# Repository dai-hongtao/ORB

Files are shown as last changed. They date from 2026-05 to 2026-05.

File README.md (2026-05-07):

# ORB

ORB 是一套开源模块化桌面性能指示系统：使用 6E2 真空管和指针式仪表，实时监控 CPU 负载、内存压力、硬盘读写、网速等信息。

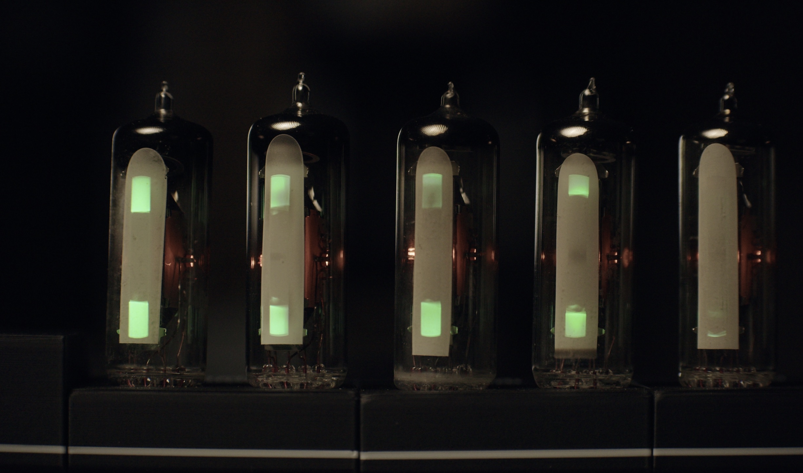
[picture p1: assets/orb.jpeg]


## 系统架构

ORB 由三种模块组成：

| 模块 | 名称 | 功能 |
| --- | --- | --- |
| 源 | Origin | 电源 + 主控 |
| 曜 | Radiance | 真空管模块 |
| 衡 | Balance | 指针仪表模块 |

你需要：

- 源 x 1（必须）
- 曜 / 衡 x N（自由组合）

ORB 最多支持 8 个拓展模块（即 16 个显示单元）。

## 首次启动

新设备首次启动时，先单独给源模块上电。  
源模块会发射一个热点，用手机连接这个热点，并在设置页中填写 SSID、密码，即可将源模块接入 Wi-Fi。  
随后，打开电脑客户端，客户端会识别到局域网中的源模块，并自动连接。

## 模块注册

曜/衡模块通过 I2C 协议与源模块通信。  
曜/衡模块首次连接源模块时，需逐一注册，并分配 I2C 地址，具体操作如下：

- 将**一个**新的曜/衡模块连接至源模块，上电开机。
- 客户端识别到新设备后，会弹出提示，用户添加设备后，即注册成功。
- 断电，插入下一个新模块，开机，继续注册剩余模块。

**注意：每次只能注册 1 个模块，不能同时注册多个新模块。I2C 设备不支持热拔插，请先插入新的模块后，再开机上电，否则系统无法识别新设备。**

I2C 地址分配规则：

曜/衡模块使用的 DAC 拥有 8 个可写的 I2C 地址，因此 ORB 最多可以同时连接 8 个模块。  
DAC 出厂的默认地址是 `0x60`，当源模块识别到地址为 `0x60` 的 I2C 设备时，即会判断为新模块。  
新模块注册时，系统会将该新设备分配一个 `0x61` - `0x67` 的地址。  
第 8 个模块会被分配为默认的 `0x60`。  
如 `0x60` - `0x67` 全部被占用，再插入新的模块，系统将不再识别，也无法控制这个模块。

如出现误操作，为模块写入了重复的地址，请删除该模块并重新添加，或在维护模式中，手动为指定模块写入 I2C 地址。  

I2C 注册表会保存在 MCU 中。如果更换上位机，相关设置也会保留。

## 模块校准

因不同电子管厂生产的 6E2 一致性较差，建议在模块注册后，进行一次校准。  
在客户端中选中某根电子管，点击 `校准`（如果不确定选中的是哪根电子管，可以点击 `寻找`，对应的电子管会亮起）。  
跟随客户端提示，依次将电子管指示条手动设置到 50%、0%、25%、100%、75%，即可完成校准。  
每根电子管只需校准 1 次，校准文件会保存在 MCU 中。更换新的电子管后，需再次进行校准。

衡模块的指针仪表，校准流程同曜模块。

## 客户端操作

在客户端中，你可以所见即所得地设置各个模块。

- 将要显示的参数拖动到电子管/仪表上，即可设置每个模块的显示内容。如一根电子管上绑定了多个CPU核心，则会取平均值。
- 电子管/仪表上的读数，与模块上实际显示的读数同步更新。
- 拖拽模块可以重新排列它们的顺序。

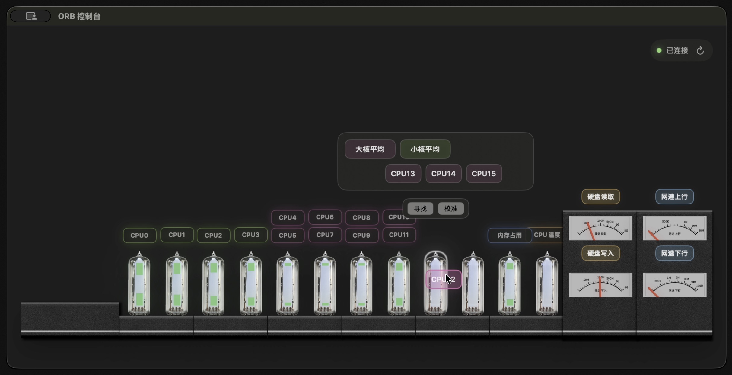
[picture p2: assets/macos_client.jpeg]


### 衡模块的仪表盘设置

用衡模块监控硬盘读写、网速时，建议使用非线性刻度仪表盘，以更有效地利用表盘空间。  
你可以根据自己的硬盘读写速度、宽带速度，使用 `tools/gauge_designer` 中的编辑器，定制你的仪表盘。  

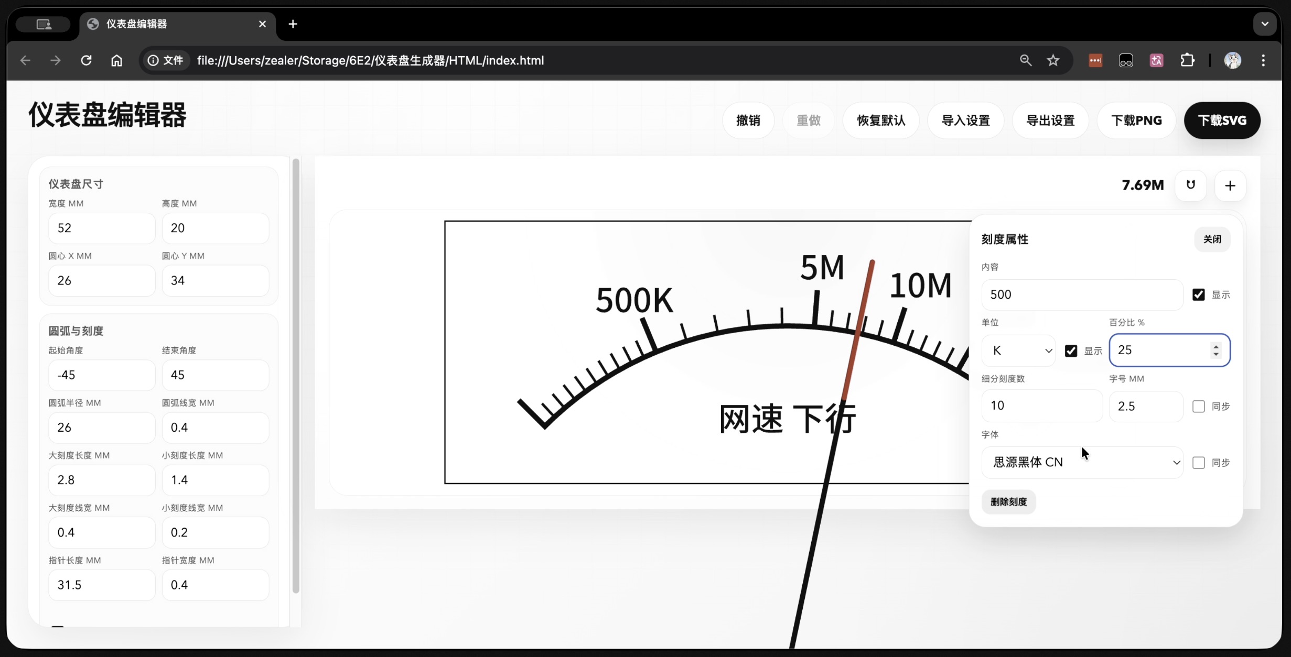
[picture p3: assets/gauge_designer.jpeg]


仪表盘制作完成后，可将配置文件导出，并直接在客户端中使用。  
仪表盘生成器可以导出 PNG 或 SVG 图片，将其 1:1 打印并粘贴到衡模块的外壳上，即可直接使用。

## 仓库结构

```text
ORB/
  client/
    macos/         macOS 客户端
    windows/       Windows 客户端（待填坑）
  firmware/
    ORB_ESP32C3/   ESP32C3 主控固件
  hardware/
    case/          外壳文件
    pcb/           PCB、Gerber、BOM、SMD 文件
  tools/
    gauge_designer/ 仪表盘生成工具
    localization/   多语言导出脚本
  locales/         多语言源文件
```

## 硬件部分

### 6E2 电子管
6E2 是一种旁热式氧化物阴极调谐指示管，其工作原理与 CRT 显示器类似，使用电子束轰击荧光材料发光。

向 6E2 栅极（pin 1）输入 0V 至 -10V 的控制信号，即可改变偏转电极的电位，从而控制荧光屏指示条的开合。  
栅极电压越高（接近 0V），指示条越闭合（光条越长）；栅极电压越低（越负），指示条越打开（光条越短）。

控制链如下：

```上位机 → ESP32 → DAC（转模拟信号） → 运放（反相 + 放大） → 6E2 栅极```

曜模块上的 R19, R22 的阻值（默认为390KΩ）将影响无信号输入时，荧光屏上光条的长度。  
不同管厂生产的 6E2 可能存在较大个体差异，导致需要的阻值可能不同。  
经测试，390KΩ的电阻已经可以适配大部分 6E2。  如果你的电子管经校准后，光条依然无法完全打开、或完全闭合，可尝试增加或减少这个电阻的阻值。

### 源模块
源模块是整个系统的主控和电源。

<img src="assets/origin_pcb.jpeg" width="800">

ORB 的系统输入电压为 12V，请使用输出能力大于 12V 3.5A 的电源为 ORB 供电。  
MCU 为 ESP32C3 Supermini 模块，通过Wi-Fi和上游客户端通信，通过 i2c 协议控制下游模块。

#### 源模块的散热（重要）：

一只 6E2 电子管的典型功耗为：

- 灯丝: 6.3V * 300mA = 1.89W
- 三极管：250V * 2mA = 0.5W

因此，在连接的曜模块较多时，源模块会存在较大散热压力。主要发热器件有（按散热压力排序）：

- Q1 FQPF8N60C MOS 管
- D5 STTH8R06D 二极管
- U1 TPS568230RJER 芯片
- Q2 FQD13N10LTM MOS 管
- D4 SS5150C 二极管

其中，前三个器件的温度需重点关注。  

当连接 6 个或以上曜模块（即 12 根电子管）时，**请务必加装风扇**，否则 250V 升压部分的功率 MOS 管 Q1 FQPF8N60C 将超过 100°C。  
加装风扇后，在长期使用前，请持续监测 Q1 FQPF8N60C MOS 管、D5 STTH8R06D 二极管、U1 TPS568230RJER 芯片的温度，防止器件过热损坏。  
Q1、D5 均预留了 TO-220 散热器空间，请妥善安装，并尽量涂抹硅脂。

#### 射频和通信

ORB 使用 ESP32C3 Supermini 模块上的贴片天线与上位机通信。  
在测试中，大部分时候，射频收发均正常，但偶现 Wi-Fi 无法正常连接、或无法正常发射热点的情况。  
如发现信号不佳，或周边电磁环境较为复杂，也可选购带 ipex 接口的 ESP32C3 Supermini Pro 模块，将射频引出至外置天线上。

### 曜/衡模块
曜和衡模块共用同一块 PCB 板，焊接不同的外围电路，即可实现不同的功能。

<img src="assets/radiance_pcb.jpeg" width="800">

当作曜模块使用时：  
· 将 R10, R17 焊盘短接；  
· J5, J6, C11, C16, D1, D2, D3, D4, R4, R5, R8, R11, R13, R15 留空不焊。

当作衡模块使用时：
· 将 R10, R17 焊盘断开；  
· R6, R7, R9, R12, R14, R16 留空不焊；  
· 250V 总线的 J3, J4, C8 留空不焊；  
· R19, R20, R22, R23, J7, J8，即电子管管座部分所有器件留空不焊；  
· C5, C6, C7留空不焊。

PCB 板上也用不同方向的丝印做了区分：  
正向丝印为曜模块电路；  
反向丝印为衡模块电路；  
侧向丝印为公用电路。

J9、J10为 12V 灯泡焊盘（可选），可外接暖色钨丝灯，用于仪表盘照明，让氛围更为复古。

## 安全提示

**驱动电子管的 250V 有致命风险。**   

在制作、使用 ORB 时，请时刻遵循如下规则：

- **电子管不支持热拔插。所有模块也不支持热拔插。** 热拔插带来的电弧可能会带来风险。
- **在增加或移除任何模块前，请先断电，并静置10秒后，再进行操作。** 设备内部的电容需要 10 秒方可泄放至安全电压。如在泄放完成前就提前移除设备，电容中的余电可能会引发电击。
- 设备运行时，或设备断电后10秒内，请勿触碰主板元件中的任何金属部分。
- 如非必要，不要带电操作。如必须带电操作，尽量单手操作，避免形成手到手回路，导致电流流经胸腔。

## 待填坑

- Windows 客户端移植（6月）
- 通信鉴权，局域网内多设备共存（6月）
- 多语言支持（7月）

## ⭐ Star History

<p align="center">
  <a href="https://star-history.com/#dai-hongtao/ORB&Timeline">
    <img src="https://api.star-history.com/svg?repos=dai-hongtao/ORB&type=Timeline" width="700"/>
  </a>
</p>

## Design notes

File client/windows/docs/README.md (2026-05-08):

# ORB Windows Client Development Docs

日期：2026-05-08  
状态：Windows 客户端开发前规格文档。ESP32 固件保持不改。

## 阅读顺序

1. `../PORTING_PLAN.md`：迁移范围、里程碑和关键风险。
2. `ARCHITECTURE.md`：工程结构、模块边界和线程模型。
3. `PROTOCOL.md`：和 ESP32 通信的唯一协议基线。
4. `STATE_AND_WORKFLOWS.md`：连接、输出、注册、校准、OTA 等状态流。
5. `WINDOWS_SYSTEM_SERVICES.md`：Windows API、mDNS、UDP、托盘、文件系统。
6. `UI_SPEC.md`：WinUI 界面规格和 Mac 端对应关系。
7. `BACKLOG.md`：实施任务拆分。
8. `TEST_PLAN.md`：测试策略和回归清单。

## 文档原则

- Mac 客户端是行为源，ESP32 固件是协议源。
- Windows 端可以改 UI 技术实现，但不能改用户心智和硬件协议。
- 每个服务都要能被 mock，避免 UI 层直接碰 HTTP、UDP、Win32 API。
- 第一版优先完整闭环，再追求动画和细节质感。
- 所有 Windows-only 决策都要有 fallback：DNS-SD 失败有 UDP/手动 IP，UDP 失败有 HTTP ping，指标采样失败有保守默认值。

## 推荐工程命名

- Solution：`ORB.Windows.sln`
- App project：`ORB.Windows`
- Test project：`ORB.Windows.Tests`
- Default namespace：`Orb.Windows`

## 约定

- “主控”指 ESP32C3 源模块。
- “模块”指曜/衡扩展模块。
- “通道”指每个扩展模块上的两个输出通道，索引固定为 `0` 和 `1`。
- “DAC code” 指 `0...4095` 的 MCP4728 输出值。
- “state revision” 指 ESP32 心跳中的 `state_revision`，用于判断是否需要刷新完整状态。

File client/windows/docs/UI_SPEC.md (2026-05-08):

# UI Specification

## 1. 总体原则

- 第一屏就是可操作的 ORB 舞台，不做 landing page。
- Windows 版用 Fluent 视觉，但信息结构和 Mac 一致。
- 常用操作在舞台上完成：连接状态、源设置、通道绑定、寻找、校准、注册新设备。
- 开发者设置是覆盖层，不打断主舞台心智。
- 所有硬件相关危险操作必须有明确状态反馈。

## 2. Window

初始尺寸：

```text
1100 x 640
```

最小尺寸：

```text
760 x 520
```

背景：

- 使用 Windows app background。
- 舞台区域保留足够空白，不使用复杂装饰背景。

## 3. Main Stage

### 3.1 Product assets

```text
origin.png   1000 x 1000
radiance.png 1000 x 1000
balance.png  1000 x 1200
```

### 3.2 Layout constants

从 Mac 迁移：

```text
sourceVisibleWidth = 880
moduleVisibleWidth = 664
sourcePixelSize = 1000 x 1000
sourceHotspot = x 60, y 634, w 882, h 328
radiance channel 0 rect = x 586, y 177, w 199, h 578
radiance channel 1 rect = x 250, y 180, w 200, h 576
balance channel 1 rect = x 216, y 70,  w 569, h 217
balance channel 0 rect = x 216, y 578, w 569, h 218
balance needle channel 1 center = 502,443 length 333
balance needle channel 0 center = 502,951 length 333
```

Radiance glow bars：

```text
channel 0 down: x 656, y 285
channel 0 up:   x 656, y 666
channel 1 down: x 320, y 285
channel 1 up:   x 320, y 666
bar width = 58
max height = 190
```

Stage scaling：

```text
visiblePixels = sourceVisibleWidth + moduleCount * moduleVisibleWidth
availableWidth = windowWidth - 48
widthFit = availableWidth / (visiblePixels / 1000)
verticalReserve = 190
bottomPadding = 42
heightFit = (windowHeight - verticalReserve - bottomPadding) / maxImagePixelHeightRatio
imageSide = min(420, max(120, min(widthFit, heightFit)))
```

### 3.3 Module order

- Source 永远在最左。
- 注册模块按本地 layout position 排序。
- 新出现的模块追加到末尾。
- 删除模块移除对应 slot。
- 拖拽模块水平排序，drop 后持久化。

### 3.4 Empty state

如果没有 `DeviceState` 且 source 不在线：

```text
请将「源」模块连接至 Wi-Fi。
```

Windows 可以额外在次级文案提示：

```text
如果已经完成配网，请确认电脑和 ORB 在同一局域网。
```

## 4. Connection Badge

位置：

- 右上角，距 top/right 约 `22px`。

内容：

- 状态圆点。
- 文案：
  - `已连接`
  - `未连接`
  - `本地网络被禁止` 仅 Mac 使用；Windows 用防火墙/网络访问文案。
- 刷新按钮。

行为：

- 点击刷新按钮调用 `ReconnectFromStatusBadge()`。
- Tooltip 展示连接帮助：
  - online：已连接。
  - offline：上次看到设备，但当前心跳不新鲜。
  - not found：尚未发现 ORB 设备。
  - firewall suspected：提示允许专用网络。

## 5. Source Inline Settings

触发：

- 点击源模块热点。

内容：

- IP 地址。
- 采样频率 slider。

Mac 舞台 slider 是 `0...2s step 0.1`，详情页是 `0.25...5s step 0.25`。Windows 建议统一：

- 舞台 inline：`0.25...2.0s step 0.25`
- 源详情/维护：`0.25...5.0s step 0.25`

修改后：

- 持久化。
- 重启 metrics/output loop。
- 标记 motion draft changed。

## 6. Radiance Channel Interaction

### 6.1 Hotspot

- 每个曜模块有两个 tube hotspot。
- Hover/active 时显示发光边框。
- 点击通道后显示：
  - action bar：寻找、校准。
  - metric candidate panel。

### 6.2 Candidate tokens

候选：

- 大核平均，如果存在 performance cores。
- 小核平均，如果存在 efficiency cores。
- CPU0...CPUN。
- 内存占用。

Token 规则：

- 点击 token：绑定到当前 active channel。
- Shift 多选：多个 CPU token 组成平均。
- 拖拽 token 到任一 tube hotspot：绑定到目标 channel。
- 内存 token 独占，绑定后清空选中。

已绑定 chip：

- 显示在 tube 上方。
- 右键移除。
- 拖回 candidate panel 移除。

### 6.3 Binding behavior

- 绑定 CPU 时使用 `MetricSourceKind.CpuCoreAverage`。
- 如果当前已是 CPU 绑定，新选择的 core 与现有 core 合并。
- 绑定内存时使用 `MetricSourceKind.MemoryUsage`，清 core list。

## 7. Balance Channel Interaction

### 7.1 Hotspot

- 每个衡模块两个 gauge hotspot。
- 点击 gauge 后显示：
  - action bar：寻找、校准、导入设置。
  - balance candidate panel。

### 7.2 Candidate tokens

候选：

- 网速上行。
- 网速下行。
- 硬盘读取。
- 硬盘写入。

规则：

- 每个 token 全局只显示一次，已经绑定的 token 从候选中隐藏。
- 点击 token：绑定到当前 gauge。
- 拖拽 token 到任一 gauge hotspot：绑定到目标 channel。
- 已绑定 label 可右键移除或拖回 candidate panel 移除。

### 7.3 Gauge SVG

导入设置：

- 选择 gauge designer 导出的 JSON。
- 自动寻找 SVG。
- 成功后：
  - `MetricBinding.ScalePoints = parsed ticks`
  - `MetricBinding.DialSvgPath = path`
  - `MetricBinding.DialSvgMarkup = svg text`

舞台上：

- 如果绑定有 SVG markup，在 gauge rect 中渲染 SVG。
- SVG 黑白化规则和 Mac 一致：强制 stroke/fill 为黑色，透明背景。

## 8. Real-time Simulation

舞台要显示软件模拟输出：

- Radiance：绿色 bar 按当前 percent 动。
- Balance：红色指针按当前 percent 转动。

动画模型与 Mac 保持大体一致：

```text
settleSeconds = max(config.settleTimeMs / 1000, 0.12)
maxVelocity = max(config.vMax / 5.0, 0.18)
maxAcceleration = max(config.aMax / 7.5, 0.22)
desiredVelocity = clamp((target - current) / settleSeconds, -maxVelocity, maxVelocity)
velocity = velocity + clamp(desiredVelocity - velocity, -maxAcceleration * dt, maxAcceleration * dt)
percent = clamp(current + velocity * dt, 0, 1)
```

条件：

- 模块离线或校准高亮时 immediate jump。
- 在线但无有效 binding 时 percent 为 `0`。

## 9. Unknown Device Overlay

触发：

- `DeviceState.UnknownI2CAddresses` 非空。

未展开：

- 右上显示“发现新设备”卡片。

注册面板：

- 标题：你连接了什么模块？
- 类型选择：曜 / 衡。
- 槽位选择：有效 ID 列表。
- 按钮：确认 / 取消。

Reset 面板：

- 当未知地址不是 `0x60` 且无可用槽位，需要 reset。
- 文案说明会写回 `0x60`。
- 按钮：确认 reset / 取消。

忙碌状态：

- 按钮 disabled。
- 显示 hourglass 或 progress ring。

## 10. Maintenance Overlay

触发：

- 托盘菜单“开发者设置”。
- 主 UI 后续可加快捷入口。

形态：

- 右侧宽 `760px` overlay。
- 背景 dim。
- 点击外部或 x 关闭，回到 source selection。

内容：

1. 已发现 ORB 服务。
2. 注册表快照。
3. 运动参数。
4. I2C 调试。
5. OTA 升级固件。
6. 手动 IP 连接，Windows 增加。

## 11. Source Detail

内容：

- 连接状态。
- IP。
- MAC。
- 固件版本。
- 主控心跳摘要。
- 采集/下发频率。
- CPU 总负载。
- 内存占用。
- 最近采样。
- 到位时间。
- 曜运动参数。
- 衡运动参数。
- 确认参数按钮。

## 12. Radiance Detail

内容：

- 模块说明。
- 绑定摘要。
- 状态。
- 地址。
- 通道 2、通道 1 的设置，保持 Mac 当前顺序。
- CPU core selection editor。
- Metric debug panel。
- LUT 状态。
- 寻找通道。
- 校准通道。
- 删除设备。

CPU editor：

- Picker：CPU 核心组平均 / 内存占用。
- 全选 / 全不选。
- 核心 chip，颜色按 P/E/unknown。

## 13. Balance Detail

内容：

- 模块说明。
- 绑定摘要。
- 状态。
- 地址。
- 通道 1、通道 2 设置。
- Metric picker：网速上行/下行、硬盘读取/写入。
- Metric debug panel。
- LUT 状态。
- 寻找。
- 校准。
- 删除。

## 14. Calibration Dialog

形态：

- Modal dialog。
- 最小宽度约 `560px`。

内容：

- 标题：`曜 · #1 · 通道 1 校准`。
- 当前步骤说明。
- 当前步、当前输出、总步数。
- 目标示意：
  - Radiance：裁剪产品图 + 目标绿色 bar。
  - Balance：表盘 SVG + 目标红色指针。
- Slider。
- 上一步 / 下一步 / 保存 LUT / 取消。
- 错误文案。

Radiance 裁剪：

```text
channel 0: x 586, y 177, w 199, h 578
channel 1: x 250, y 180, w 200, h 576
```

Balance 裁剪：

```text
channel 0: x 216, y 578, w 569, h 218
channel 1: x 216, y 70,  w 569, h 217
```

## 15. Toast / Notice

轻量消息：

- `ModuleActionNotice`
- `ModuleActionIssue`
- `MotionApplySuccessNotice`
- `ReconnectStatusNotice`
- `UnknownDeviceNotice/Issue`
- `I2CDebugNotice/Issue`
- `FirmwareUploadNotice/Issue`

规则：

- success 用绿色。
- issue 用红色。
- 默认 3 秒自动消失，除非用户进入同一流程。
- 不遮挡连接 badge 和注册 overlay。

## 16. Accessibility

第一版要求：

- 所有 icon-only button 有 tooltip / automation name。
- Dialog 有默认按钮和取消按钮。
- 颜色状态必须配文字。
- 键盘可操作：Tab 遍历 buttons、slider、picker。
- 托盘菜单项有文本。

## 17. Windows-specific Additions

相对 Mac 增加：

- 防火墙/专用网络帮助 banner。
- 手动 IP 入口。
- 托盘图标。
- 如果 DNS-SD 不可用，开发者设置显示 discovery fallback 状态。

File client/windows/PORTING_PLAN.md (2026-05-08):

# ORB Windows 11 Client Porting Plan

日期：2026-05-08  
范围：将现有 macOS 客户端能力迁移到 Windows 11 客户端；ESP32 固件和硬件协议保持不变。  
当前状态：`client/windows` 为空目录，本文件作为 Windows 端的开发规格和拆工基线。

## 0. 详细开发文档

本计划文档只保留方向和里程碑。具体实现以 `docs/` 下的开发文档为准：

- [docs/README.md](docs/README.md)：文档索引和阅读顺序
- [docs/ARCHITECTURE.md](docs/ARCHITECTURE.md)：Windows 工程架构、模块边界、线程模型
- [docs/PROTOCOL.md](docs/PROTOCOL.md)：ESP32 发现、心跳、HTTP API、DTO 和错误处理
- [docs/STATE_AND_WORKFLOWS.md](docs/STATE_AND_WORKFLOWS.md)：应用状态、持久化结构、核心业务流程
- [docs/WINDOWS_SYSTEM_SERVICES.md](docs/WINDOWS_SYSTEM_SERVICES.md)：Windows 系统指标、mDNS、UDP、托盘和文件系统接口
- [docs/UI_SPEC.md](docs/UI_SPEC.md)：WinUI 首屏舞台、浮层、详情页、校准和维护 UI 规格
- [docs/BACKLOG.md](docs/BACKLOG.md)：可拆 issue 的实施任务和验收标准
- [docs/TEST_PLAN.md](docs/TEST_PLAN.md)：单元、集成、硬件和发布回归测试

## 1. 目标和非目标

### 1.1 目标

- 在 Windows 11 上提供和 Mac 客户端尽量一致的功能、信息架构、视觉层级和交互流程。
- 复用 ESP32 现有 HTTP API、UDP 心跳、mDNS/DNS-SD 服务，不要求固件改动。
- Windows 客户端独立采集本机 CPU、内存、网络、磁盘等指标，并按 Mac 端同一套归一化、LUT、输出帧逻辑下发给 ESP32。
- 支持模块发现、自动连接、注册、删除、寻找、校准、运动参数、I2C 维护、OTA 固件上传。
- 保留本地状态持久化：模块排序、通道绑定、采样周期、运动参数草稿、LUT、本地语言。
- 保留中英文 UI 基础，后续让 Mac/Windows 使用同一份 `locales` 作为源。

### 1.2 非目标

- 不重写 ESP32 固件协议。
- 不改变硬件注册地址规则。
- 不在第一版引入账号、云同步、远程访问或鉴权。
- 不把 Wi-Fi 配网页面迁进客户端第一版；当前固件已有 AP captive portal，Windows 版可先和 Mac 一样假设设备已入网。
- 不强求逐像素复刻 SwiftUI；重点是功能和用户心智一致，Windows 端使用原生 Fluent/WinUI 表达。

## 2. 已读源码地图

### 2.1 Mac 客户端

- 入口和窗口：`client/macos/ORB/ORB/ORBApp.swift`、`ContentView.swift`
- 状态机：`ViewModels/AppModel.swift`
- 协议访问：`Services/ORBSession.swift`
- 发现：`Services/DeviceDiscoveryService.swift`
- UDP 心跳：`Services/HeartbeatListenerService.swift`
- 系统指标采样：`Services/SystemMetricsService.swift`
- 本地存储：`Persistence/AppStore.swift`
- 数据模型：`Models/*.swift`
- LUT：`Calibration/LUTMapper.swift`
- 菜单栏：`AppKitBridge/StatusItemController.swift`
- UI 详情页：`Views/DetailViews.swift`
- 产品图资源：`resources/origin.png`、`radiance.png`、`balance.png`、`resources/orb_icon_set/*`

### 2.2 ESP32 固件

- HTTP API：`firmware/ORB_ESP32C3/src/ApiServer.cpp`
- mDNS 广播：`BonjourService.cpp`
- UDP 心跳：`HeartbeatService.cpp`
- Wi-Fi 配网：`WiFiProvisioning.cpp`
- I2C 模块扫描：`ModuleBus.cpp`
- 地址和模型规则：`Models.h`、`Config.h`
- 平滑和抖动：`SmoothingEngine.*`
- LUT 持久化：`CalibrationStore.*`

### 2.3 Windows 目录

- `client/windows` 当前为空；建议从新工程开始，但把本文件作为第一份架构文档提交。

## 3. Mac 客户端功能清单

### 3.1 连接和在线状态

Mac 当前流程：

1. 首次打开先展示本地网络授权引导。
2. 启动系统指标采样。
3. 启动 UDP 心跳监听，优先绑定 `43981`，失败则使用动态端口。
4. 启动 Bonjour 浏览 `_orb._tcp.local.`。
5. 发现服务后自动解析并 `GET /api/v1/state`。
6. 如果收到 UDP 心跳，按 `device_name` 或 `mac` 关联当前设备。
7. 如果动态 UDP 端口被使用，通过 `POST /api/v1/heartbeat/config` 告诉 ESP32 后续投递端口。
8. 心跳不新鲜时，回退 HTTP `GET /api/v1/ping` / `state` 探活。

Windows 需要保持同一套在线判断：

- `online`：最近一次心跳或 HTTP 通信仍在 grace window 内。
- `offline`：已知设备存在，但超过 grace window。
- `not_found`：未发现任何设备。

### 3.2 系统指标采样

Mac 采样字段：

- 总 CPU 使用率。
- 每个逻辑核心使用率。
- CPU 核心拓扑：性能核心 / 能效核心 / 未分类。
- 内存已用和总量。
- 网络下载 / 上传字节每秒。
- 磁盘读取 / 写入字节每秒。
- GPU 使用率，目前只是模型字段，主 UI 还没有作为稳定绑定入口。

默认采样/下发周期为 `0.5s`，允许 `0.25s ... 5.0s`。

### 3.3 指标到输出帧

Mac 端输出链路：

1. 采样得到 `SystemMetricsSnapshot`。
2. 按每个模块的 `ChannelBinding` 选择指标。
3. 指标归一化到 `0...1`。
4. 应用通道 LUT 映射为 `0...4095` DAC code。
5. 聚合为 `OutputFrame(frameID, channels)`。
6. `POST /api/v1/frame`，表单字段：
   - `frame_id`
   - `channels`，格式 `moduleId,channelIndex,targetCode;...`

输出暂停条件：

- 主控离线。
- 正在校准。
- 正在寻找通道。
- 正在启动校准。
- 存在未知 I2C 设备待处理。

### 3.4 模块和指标绑定

模块类型：

- `unknown = 0`
- `radiance = 1`：曜，双通道 6E2，主要绑定 CPU 核心组平均 / 内存占用。
- `balance = 2`：衡，双通道指针表，主要绑定网络上传、网络下载、磁盘读取、磁盘写入。

本地模块设置：

- `ModuleSetting(moduleID, moduleType, channelBindings)`
- 每个通道一个 `ChannelBinding(channelIndex, MetricBinding)`
- `MetricBinding` 包含指标类型、CPU 核心列表、是否用户指定、非线性刻度点、表盘 SVG 路径/内容。

### 3.5 UI 结构

Mac 首屏是一个产品图舞台：

- 中间展示源模块和已注册的曜/衡模块实物图。
- 顶右角是连接状态胶囊和手动重连按钮。
- 点击源模块显示源设置浮层。
- 点击曜/衡模块的通道区域显示指标候选面板和寻找/校准按钮。
- 拖拽模块可改变顺序并持久化。
- 发现未知设备时右上浮层提示注册。
- 开发者设置覆盖层包括服务列表、注册表快照、运动参数、I2C 调试、OTA。
- 校准使用模态 sheet。

Windows UI 应复刻这些用户心智：

- 仍以产品图舞台作为第一屏，而不是设置列表或向导。
- 操作入口尽量保持“点设备/点通道”的直接性。
- Windows 可使用 Fluent 材质、CommandBar、TeachingTip/Dialog，但信息结构不要改。

### 3.6 注册和维护

地址规则：

- 模块 ID `1...7` 对应 I2C `0x61...0x67`。
- 模块 ID `8` 在 UI 中显示为 ID `0`，对应保留地址 `0x60`。
- 新模块默认地址 `0x60`。
- 前 7 个槽位未满时，不允许直接占用 ID 8。
- 前 7 个槽位已满后，第 8 个模块保留 `0x60`。
- 发现已经改过地址但不属于当前注册表的模块时，需要先 reset 回 `0x60` 再注册。

维护能力：

- 刷新状态作为 I2C 扫描。
- 手动写 MCP4728 I2C 地址。
- 删除模块时清本地绑定/LUT，并调用固件删除。
- OTA 上传 `.bin`。

## 4. ESP32 协议规格

### 4.1 发现和心跳

mDNS/DNS-SD：

- 服务类型：`_orb._tcp.local.`
- 实例名：`ORB-xxxx`
- 端口：`80`
- TXT：
  - `device`
  - `fw`

UDP 心跳：

- 默认端口：`43981`
- 周期：`1500ms`
- 投递方式：局域网广播。
- 客户端如果无法监听默认端口，可监听动态端口，并通过 `/api/v1/heartbeat/config` 配置 ESP32。

心跳 JSON 字段：

- `type = "heartbeat"`
- `protocol_version = 1`
- `device_name`
- `firmware_version`
- `ip`
- `mac`
- `port`
- `sequence`
- `state_revision`
- `heartbeat_interval_ms`
- `default_port`
- `target_port`
- `configured_port`
- `delivery`
- `uptime_ms`
- `registered_count`
- `present_count`

### 4.2 HTTP API

所有 mutating API 当前都是 `application/x-www-form-urlencoded`，OTA 是 `multipart/form-data`。

| 方法 | 路径 | 用途 | 请求字段 | 成功响应 |
| --- | --- | --- | --- | --- |
| GET | `/api/v1/ping` | 探活和轻量状态 | 无 | 设备名、IP、MAC、心跳配置、`state_revision` |
| POST | `/api/v1/heartbeat/config` | 配置 UDP 心跳目标端口 | `udp_port` | 心跳配置 ACK |
| GET | `/api/v1/state` | 完整状态 | 无 | `ORBDeviceState` |
| POST | `/api/v1/smoothing` | 下发运动参数 | `module_type`, `settle_time_ms`, `a_max`, `v_max`, `jitter_frequency_hz`, `jitter_amplitude`, `jitter_dispersion` | 完整状态 |
| POST | `/api/v1/frame` | 批量输出帧 | `frame_id`, `channels` | `ok`, `frame_id`, `applied` |
| POST | `/api/v1/outputs` | 单通道输出，兼容/调试用 | `module_id`, `channel_index`, `target_code` | `ok` |
| POST | `/api/v1/preview` | 寻找/校准预览 | `mode`, `module_id`, `channel_index`, `target_code` | 预览 ACK |
| POST | `/api/v1/modules/register` | 注册模块 | `module_type`, `id`, `address` | 完整状态 |
| POST | `/api/v1/modules/delete` | 删除模块 | `id` | 完整状态 |
| POST | `/api/v1/modules/reset` | 未知旧地址重置为 `0x60` | `address` | 完整状态 |
| POST | `/api/v1/i2c/write_address` | 手动 I2C 改址 | `old_address`, `new_address` | 完整状态 |
| POST | `/api/v1/calibration/save` | 保存 LUT | `module_id`, `channel_index`, `points`, `updated_at_epoch` | 完整状态 |
| POST | `/api/v1/firmware/upload` | OTA 上传 | multipart `firmware` | `ok`, `rebooting`, `message`, `firmware_version` |

`ORBDeviceState` 字段：

- `device_name`
- `firmware_version`
- `ip`
- `mac`
- `state_revision`
- `heartbeat_interval_ms`
- `heartbeat_default_port`
- `heartbeat_target_port`
- `heartbeat_configured_port`
- `heartbeat_delivery`
- `wifi_mode`
- `unknown_candidate_present`
- `detected_i2c_addresses`
- `unknown_i2c_addresses`
- `calibration_luts`
- `smoothing`
- `modules`

## 5. Windows 技术选型建议

### 5.1 推荐基线

- UI：WinUI 3 + Windows App SDK。
- 语言：C#。
- 运行时：.NET 10 LTS。
- Windows App SDK：使用当前稳定版 1.8.x；暂不使用 2.0 preview。
- 目标系统：Windows 11 x64 / arm64。代码不主动依赖 Windows 10，但 WinUI/Win32 API 多数可兼容 Windows 10。
- 打包：先用 unpackaged dev build；进入发布阶段再定 MSIX 或 unpackaged + installer。

选择理由：

- WinUI 3 是 Windows App SDK 中的现代桌面 UI 框架，贴近 Windows 11 原生体验。
- Windows App SDK 可用于桌面应用，并通过 NuGet 发布，不和 OS SDK 强绑定。
- .NET 10 是当前 LTS，支持期到 2028-11。

### 5.2 备选方案

- WPF：开发快、拖拽和系统托盘成熟，但视觉和 Windows 11 原生感弱。若 WinUI 的舞台/拖拽成本过高，可作为降级。
- C++/WinUI：原生 API 调用更直接，但开发效率低；本项目逻辑以状态、网络、UI 为主，C# 更合适。
- MAUI：跨平台不是目标，且 Mac 客户端已有 SwiftUI；不建议。

## 6. Windows 模块架构

建议工程结构：

```text
client/windows/
  ORB.Windows.sln
  src/
    ORB.Windows/
      App.xaml
      MainWindow.xaml
      Assets/
      Views/
      Controls/
      ViewModels/
      Services/
      Models/
      Persistence/
      Calibration/
      Native/
      Localization/
  tests/
    ORB.Windows.Tests/
```

### 6.1 Models

从 Swift 模型逐一迁移：

- `ModuleType`
- `MetricSourceKind`
- `MetricBinding`
- `MetricScalePoint`
- `ChannelBinding`
- `RegistryEntry`
- `SmoothingConfig`
- `DeviceSmoothingProfiles`
- `ORBDeviceState`
- `ORBHeartbeat`
- `LayoutSlot`
- `ModuleSetting`
- `LUTPoint`
- `CalibrationLUT`
- `CalibrationDraft`
- `OutputPreviewMode`
- `OutputChannelPayload`
- `OutputFrame`
- `DiscoveredService`
- `ORBEndpoint`
- `CPUCoreKind`
- `CPUCoreDescriptor`
- `CPUCoreLoad`
- `SystemMetricsSnapshot`
- `ConnectionStatus`
- `AppLanguage`

JSON 策略：

- 使用 `System.Text.Json`。
- API DTO 使用 snake_case 属性映射，避免因 C# 命名和固件字段不一致出错。
- 本地存储可继续使用 camelCase 或跟 Mac 一致；为未来跨平台迁移，建议使用和 Mac `StoredAppState` 兼容的字段名。

### 6.2 Services

| 服务 | Windows 职责 | Mac 对照 |
| --- | --- | --- |
| `OrbHttpClient` | HTTP API、表单编码、OTA multipart、错误映射 | `ORBSession` |
| `DeviceDiscoveryService` | DNS-SD/mDNS 浏览 `_orb._tcp.local.`、解析 host/port、维护发现列表 | `DeviceDiscoveryService` |
| `HeartbeatListenerService` | UDP 43981 监听、动态端口回退、解析心跳 JSON | `HeartbeatListenerService` |
| `SystemMetricsService` | Windows 本机指标采样 | `SystemMetricsService` |
| `AppStateStore` | `%AppData%/ORB/app_state.json` 读写 | `AppStore` |
| `TrayService` | 通知区图标、打开主窗、开发者设置、退出 | `StatusItemController` |
| `FileDialogService` | 选择 BIN/JSON/SVG | `NSOpenPanel` / SwiftUI fileImporter |
| `LocalizationService` | zh-Hans/en/system 语言切换 | `AppLanguage` + `Localizable.strings` |

### 6.3 ViewModels

建议不要把 Mac 的 `AppModel` 原样搬成一个巨型类。可以保留一个根 `AppViewModel`，但拆出内聚子状态：

- `ConnectionCoordinator`
- `MetricsLoop`
- `OutputFrameScheduler`
- `ModuleRegistryWorkflow`
- `CalibrationWorkflow`
- `MotionSettingsWorkflow`
- `MaintenanceWorkflow`

根 ViewModel 汇总可绑定状态，避免 UI 到处直接调用服务。

## 7. Windows 差异点和实现方案

### 7.1 系统指标采样

目标输出必须和 Mac `SystemMetricsSnapshot` 对齐。

| 指标 | Mac 来源 | Windows 建议 | 风险 |
| --- | --- | --- | --- |
| 总 CPU | Mach `host_processor_info` delta | `GetSystemTimes` delta | 只能总量，不能分核心 |
| 每核心 CPU | Mach per-core ticks | 优先技术 spike：`NtQuerySystemInformation(SystemProcessorPerformanceInformation)` 或 PDH per core；总 CPU fallback 用 `GetSystemTimes` | per-core API 需要验证精度、权限、采样频率 |
| P/E 核心分类 | `sysctl hw.perflevel*` | `GetSystemCpuSetInformation` + `EfficiencyClass` | 非混合架构可能全 unknown |
| 内存 | `host_statistics64` + physicalMemory | `GlobalMemoryStatusEx` | 简单稳定 |
| 网络吞吐 | `getifaddrs` 的 `ifi_ibytes/obytes` delta | `GetIfTable2` 的接口累计字节 delta，排除 loopback/down/tunnel | 多网卡/虚拟网卡过滤要调 |
| 磁盘吞吐 | IOKit `IOBlockStorageDriver` 统计 delta | 首版用 PDH English counters：`PhysicalDisk(_Total)\Disk Read Bytes/sec` / `Disk Write Bytes/sec`；并做 direct IOCTL spike | PDH 高频和本地化需要注意 |
| GPU | IOKit IOAccelerator | 首版隐藏或保留 placeholder；后续用 PDH GPU Engine/DXGI/NVML spike | 供应商差异大 |

采样策略：

- UI 仍允许 `0.25s ... 5s`。
- 如果某项 Windows API 不适合高频，服务内部可用独立节流，上一笔数据复用到更高频输出帧。
- 网络和磁盘用累计计数时要处理计数回绕、接口变化、睡眠恢复。
- CPU core descriptors 需要稳定排序，避免每次启动核心 token 顺序变化。

### 7.2 mDNS / DNS-SD

用户直觉是“Windows 没有原生 Bonjour，需要嵌入 mDNS”。需要稍微校正：

- Windows 10+ 桌面应用有 Win32 DNS-SD API：`DnsServiceBrowse`、`DnsServiceResolve`。
- WinRT `DnssdServiceWatcher` 文档标注不推荐继续依赖，且建议使用其他枚举方式。
- 因此建议第一阶段先做 Win32 DNS-SD spike；如果在 Windows 11 + 常见路由器 + 防火墙环境下发现不稳定，再嵌入 mDNS 客户端库作为 fallback。

建议实现：

1. 用 Win32 `DnsServiceBrowse` 浏览 `_orb._tcp.local.`。
2. 用 `DnsServiceResolve` 获取 host、port、TXT、IP。
3. 发现列表按实例名去重。
4. 如果 3 秒内 DNS-SD 无结果，但收到 UDP 心跳，直接通过心跳 IP 连接。
5. 提供“手动输入 IP”隐藏入口或开发者入口，作为现场救援方案。

防火墙注意：

- UDP 心跳监听可能触发 Windows Defender Firewall 入站提示。
- 第一版应准备明确的 UI 文案：需要允许专用网络上的 UDP 入站，HTTP 主动请求通常不需要入站授权。
- 如果默认端口 43981 不可用，仍要绑定动态端口并调用 `/api/v1/heartbeat/config`。

### 7.3 UI 重构

WinUI 版 UI 建议分三层：

1. **舞台层**：模块产品图、热点区域、拖拽排序、实时模拟输出。
2. **浮层层**：连接徽章、未知设备注册、指标候选面板、通道动作条。
3. **详情/维护层**：源设置、模块详情、开发者设置、校准 Dialog。

重点复刻：

- 产品图资源沿用 Mac `resources/*.png`。
- 源模块和扩展模块横向排列。
- 曜模块两个 tube 通道有可点击/可 drop 的热点。
- 衡模块两个 gauge 通道有可点击/可 drop 的热点。
- 拖拽模块改变横向顺序。
- 通道绑定后，舞台上有实时视觉反馈。
- 校准时其他输出暂停，只有当前通道响应滑块。

Windows 具体控件建议：

- `MainWindow`：根容器。
- `Canvas`：舞台绝对定位和热点。
- `Image`：产品图。
- `Popup` / `TeachingTip` / 自定义 overlay：候选面板和注册面板。
- `ContentDialog`：校准流程、重要确认。
- `CommandBar` 或轻量按钮条：通道动作。
- `NavigationView` 不作为主入口，避免变成传统设置型应用。

### 7.4 系统托盘

Mac 有菜单栏状态图标。Windows 对应通知区图标：

- 左键：显示主窗口。
- 右键菜单：
  - 连接状态
  - 打开主窗口
  - 开发者设置
  - 退出
- 图标状态可暂不动态换图，第一版用 ORB icon + tooltip 文字。

WinUI 没有完整托盘抽象，建议用 Win32 `Shell_NotifyIcon` 封装。

### 7.5 文件导入

需要支持：

- OTA `.bin`。
- 衡模块仪表盘 JSON。
- 同名/同目录 SVG 表盘。

Windows 差异：

- 无 security-scoped resource。
- 需要把导入的 SVG 内容读入本地状态，避免路径移动后丢失。
- Calibration preview 中显示 SVG 可用 WebView2 或 SVG 渲染库；首版推荐 WebView2，和 Mac 的 `WKWebView` 角色一致。

### 7.6 本地存储

Mac 路径：Application Support/ORB/app_state.json。  
Windows 建议路径：

- `%APPDATA%\ORB\app_state.json`

字段保持：

- `layout`
- `moduleSettings`
- `refreshInterval`
- `motionDurationFactor`
- `calibrationLUTs`
- `appLanguage`

需要做迁移：

- 兼容早期 legacy `binding` 单绑定字段。
- 兼容 legacy shared LUT。
- Windows 版第一次运行不应覆盖 Mac 状态，两个平台本地独立。

### 7.7 本地化

当前 Mac 有 `en.lproj/Localizable.strings`、`zh-Hans.lproj/Localizable.strings`，仓库根还有 `locales/en.json`、`locales/zh-Hans.json`。

建议：

- 第一版 Windows 直接用 JSON resource 或 `.resw`。
- 后续把根 `locales/*.json` 定为唯一源，再生成 Mac `.strings` 和 Windows `.resw`。
- UI 文案要先补齐 Windows 特有内容：防火墙、专用网络、通知区、手动 IP。

## 8. 开发里程碑

### M0：技术 spike 和工程基线

交付：

- WinUI 3 空工程。
- 能打开主窗口、加载 ORB icon 和三张产品图。
- 验证 .NET 10 + Windows App SDK 1.8 开发环境。
- DNS-SD spike：确认 `DnsServiceBrowse/Resolve` 能否发现 ESP32 `_orb._tcp.local.`。
- UDP spike：默认 43981 监听、动态端口 fallback、防火墙表现记录。
- Metrics spike：CPU/memory/network/disk 四项在 Windows 11 上可取值。

验收：

- 不接硬件也能打开 UI。
- 接硬件时至少能通过 DNS-SD 或 UDP 心跳拿到设备 IP。
- 输出一份 spike 结论：DNS-SD 是否需要嵌入 fallback。

### M1：协议和模型层

交付：

- C# 数据模型。
- `OrbHttpClient`。
- `LUTMapper`。
- `AppStateStore`。
- 单元测试覆盖：
  - module ID/address 映射。
  - snake_case JSON decode。
  - LUT 插值。
  - rate normalization。
  - frame channels 格式。

验收：

- 可用 mock HTTP server 完整 decode `/state`。
- 可发送 `/frame` 并验证 form body。

### M2：连接协调层

交付：

- `DeviceDiscoveryService`。
- `HeartbeatListenerService`。
- `ConnectionCoordinator`。
- 心跳端口同步 `/heartbeat/config`。
- HTTP ping/state fallback。
- 手动重连。

验收：

- 设备开机后自动连接。
- 拔掉/关掉设备后状态变为 offline。
- 设备重新上线后恢复 online。
- 默认 UDP 端口被占用时，动态端口能收到后续心跳。

### M3：系统指标和实时下发

交付：

- `SystemMetricsService`。
- `OutputFrameScheduler`。
- `SystemMetricsSnapshot` UI debug display。
- 采样周期设置和持久化。
- 绑定 CPU/内存/网络/磁盘并下发。

验收：

- CPU/内存驱动曜模块变化。
- 网络/磁盘驱动衡模块变化。
- 校准/寻找/未知设备状态下输出暂停。
- 采样周期改变后实时生效。

### M4：首屏舞台 UI

交付：

- 源/曜/衡产品图舞台。
- 模块横向布局。
- 在线/离线 dimmed 状态。
- 顶右连接 badge。
- 点击源模块打开源设置。
- 点击通道打开候选指标面板。
- 拖拽模块排序。

验收：

- 不打开详情页即可完成常用绑定。
- 模块排序重启后保持。
- 舞台实时模拟输出和硬件输出大体一致。

### M5：模块详情和注册流程

交付：

- 未知设备 overlay。
- 注册曜/衡模块。
- reset 旧地址设备。
- 删除设备。
- Radiance 详情：CPU 核心选择、内存绑定、debug panel、寻找、校准入口。
- Balance 详情：网络/磁盘绑定、debug panel、寻找、校准入口、表盘导入。

验收：

- 新模块从 `0x60` 注册到目标 ID。
- 旧地址未知模块可 reset 后注册。
- 删除模块后本地绑定和 LUT 清理。
- 表盘 JSON + SVG 导入后参与非线性映射。

### M6：校准和运动参数

交付：

- 校准 Dialog。
- Radiance 校准顺序：`0%, 50%, 25%, 100%, 75%`。
- Balance 校准顺序：导入刻度 percent；无刻度时 `0...100%` 每 10%。
- 预览请求 ACK 校验和重试。
- 保存 LUT 到固件和本地。
- 源设置/开发者设置中的运动参数：到位时间、响应力度、最大速度、抖动频率、抖动幅度、抖动随机度。

验收：

- 校准滑块只影响当前通道。
- 取消校准后恢复实时输出。
- 保存后重新进入显示自定义 LUT。
- 运动参数应用后固件返回值和期望值一致。

### M7：维护、托盘、OTA、本地化

交付：

- 开发者设置 overlay。
- 已发现服务列表。
- 注册表快照。
- I2C 扫描和手动改址。
- OTA `.bin` 上传。
- Windows 通知区图标和菜单。
- 中英文切换。
- Windows 防火墙/网络访问错误文案。

验收：

- OTA 成功后设备重启，客户端自动重连。
- 右键托盘菜单可打开开发者设置和退出。
- 切换语言后主窗口和托盘菜单刷新。

### M8：打包、测试和发布候选

交付：

- Release build。
- x64 和 arm64 测试。
- 崩溃日志/诊断日志。
- README Windows 安装和防火墙说明。
- 发布包。

验收：

- 干净 Windows 11 机器可安装/运行。
- 无 Visual Studio 环境也能运行。
- 完整硬件回归通过。

## 9. 测试计划

### 9.1 单元测试

- `LUTMapper.map`：默认映射、插值、端点补齐、clamp。
- `MetricNormalizer`：CPU、内存、network fallback ranges、disk fallback ranges、自定义 scale points。
- `AddressMapper`：ID 1...8 和 I2C 地址互转。
- `FrameEncoder`：channels 格式、空帧不发送。
- `StateStore`：默认值、legacy migration、date/epoch decode。
- `HeartbeatParser`：snake_case 字段、旧固件缺字段 fallback。

### 9.2 集成测试

- Mock ESP32 HTTP server。
- Mock UDP heartbeat broadcaster。
- DNS-SD 可用时做本地服务模拟；不可用则把 DNS-SD 放到手工硬件测试。
- OTA multipart body 验证。
- 心跳动态端口配置验证。

### 9.3 硬件回归

每个 RC 至少跑：

1. 首次发现和自动连接。
2. 手动重连。
3. 注册一个曜。
4. 注册一个衡。
5. CPU/内存/网络/磁盘绑定和实时输出。
6. 曜通道寻找和校准。
7. 衡表盘导入和校准。
8. 删除模块。
9. I2C 扫描。
10. OTA 上传并重连。
11. 默认 UDP 端口冲突场景。
12. Windows Defender Firewall 专用网络允许/拒绝场景。

## 10. 风险和对策

| 风险 | 影响 | 对策 |
| --- | --- | --- |
| Windows DNS-SD 在目标环境不稳定 | 设备发现失败 | M0 spike；实现 UDP 心跳直连；保留手动 IP；必要时嵌入 mDNS fallback |
| Windows 防火墙拦截 UDP 心跳 | 在线状态延迟或无法自动刷新 | HTTP ping/state fallback；清晰文案；动态端口同步 |
| per-core CPU 采样不稳定 | 曜模块 CPU 核心绑定体验差 | 先保总 CPU/核心组 fallback；M0 验证 per-core API |
| PDH 磁盘计数本地化/频率问题 | 衡磁盘读写不准 | 使用 `PdhAddEnglishCounterW`；必要时改 direct IOCTL 或降低内部采样频率 |
| WinUI 舞台拖拽和 overlay 复杂 | UI 开发周期拉长 | 先做功能可用舞台，再逐步精修动画和材质 |
| SVG 表盘渲染差异 | 衡校准预览不一致 | 首版 WebView2；后续考虑 SVG rasterization cache |
| OTA 过程中断 | 设备需重新刷写 | 上传前强提示；超时 180s；失败明确提示不要断电 |

## 11. 待确认问题

1. Windows 版第一版是否只支持 Windows 11，还是也声明 Windows 10 可运行？
2. 是否接受 WinUI 3 + .NET 10 LTS 作为正式技术栈？
3. 是否允许把 `client/macos/ORB/ORB/resources` 里的 PNG 和 icon 复制到 Windows 工程？
4. DNS-SD 如果 Win32 API 可用，是否仍强制嵌入第三方 mDNS？建议先 spike 再决定。
5. Windows 第一版是否需要“手动输入 IP”入口？建议开发者设置中加入。
6. GPU 指标是否进入 Windows v1？建议先不进入可选 token。
7. Windows 发布形式偏好：MSIX、传统 installer，还是 zip portable？

## 12. Definition of Done

Windows v1 完成标准：

- 连接发现、心跳、HTTP fallback、状态同步完整。
- CPU、内存、网络、磁盘四类指标可驱动硬件。
- 曜/衡双通道绑定、寻找、校准、LUT 保存完整。
- 新设备注册、旧地址 reset、删除设备完整。
- 运动参数、I2C 调试、OTA 完整。
- 本地状态持久化和中英文切换可用。
- 托盘菜单可用。
- Windows 11 x64 硬件回归通过。
- 不需要 ESP32 固件改动。

## 13. 官方资料

- WinUI 3：<https://learn.microsoft.com/en-us/windows/apps/winui/>
- Windows App SDK：<https://learn.microsoft.com/en-us/windows/apps/windows-app-sdk/>
- Windows App SDK downloads：<https://learn.microsoft.com/en-us/windows/apps/windows-app-sdk/downloads>
- .NET support policy：<https://dotnet.microsoft.com/en-us/platform/support/policy>
- Windows SDK：<https://developer.microsoft.com/en-us/windows/downloads/windows-sdk/>
- Win32 DNS-SD `DnsServiceBrowse`：<https://learn.microsoft.com/en-us/windows/win32/api/windns/nf-windns-dnsservicebrowse>
- Win32 DNS-SD `DnsServiceResolve`：<https://learn.microsoft.com/en-us/windows/win32/api/windns/nf-windns-dnsserviceresolve>
- WinRT DNS-SD namespace：<https://learn.microsoft.com/en-us/uwp/api/windows.networking.servicediscovery.dnssd>
- `GetSystemTimes`：<https://learn.microsoft.com/en-us/windows/win32/api/processthreadsapi/nf-processthreadsapi-getsystemtimes>
- `GetSystemCpuSetInformation`：<https://learn.microsoft.com/en-us/windows/win32/api/processthreadsapi/nf-processthreadsapi-getsystemcpusetinformation>
- `GlobalMemoryStatusEx`：<https://learn.microsoft.com/en-us/windows/win32/api/sysinfoapi/nf-sysinfoapi-globalmemorystatusex>
- `GetIfTable2`：<https://learn.microsoft.com/en-us/windows/win32/api/netioapi/nf-netioapi-getiftable2>
- PDH `PdhAddEnglishCounterW`：<https://learn.microsoft.com/en-us/windows/win32/api/pdh/nf-pdh-pdhaddenglishcounterw>
- Windows Performance Counters：<https://learn.microsoft.com/en-us/windows/win32/perfctrs/performance-counters-portal>

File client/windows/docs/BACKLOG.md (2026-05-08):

# Implementation Backlog

每个条目都应该可以拆成 issue。优先级按开发顺序排列。

## M0：工程基线和技术 Spike

### W0.1 创建 WinUI 3 工程

交付：

- `ORB.Windows.sln`
- `src/ORB.Windows`
- `tests/ORB.Windows.Tests`
- 空 MainWindow。
- 能加载 ORB icon。

验收：

- Debug 可启动。
- Release 可构建。
- 无硬件时打开空舞台不崩。

### W0.2 复制和加载产品图资源

交付：

- `origin.png`
- `radiance.png`
- `balance.png`
- `orb_icon_set/*`

验收：

- MainWindow 能显示三张图。
- 资源以 app package content 方式加载。

### W0.3 DNS-SD spike

交付：

- 最小 console/service 代码浏览 `_orb._tcp.local.`。
- Resolve host、port、TXT。
- 记录 Windows 11 实测结果。

验收：

- 接入真实 ESP32 时能发现，或明确失败原因。
- 输出是否需要 embedded mDNS fallback 的结论。

### W0.4 UDP heartbeat spike

交付：

- 默认端口 `43981` listener。
- 动态端口 fallback。
- JSON decode heartbeat。

验收：

- 能收到真实 ESP32 心跳。
- 默认端口被占用时动态端口可工作。
- 记录防火墙弹窗表现。

### W0.5 System metrics spike

交付：

- CPU total。
- Memory。
- Network total bps。
- Disk read/write bps。
- Per-core CPU 可行性结论。
- CPU P/E topology 可行性结论。

验收：

- 采样值每秒更新。
- 网络/磁盘有实际 IO 时数值变化。

## M1：模型、协议、存储

### W1.1 迁移 domain models

交付：

- `Models/` 下所有 domain model。
- enum raw values 和 Mac/固件一致。

验收：

- 模块类型、指标类型、连接状态可序列化。

### W1.2 DTO 和 JSON 映射

交付：

- `OrbDeviceStateDto`
- `OrbHeartbeatDto`
- `OrbPingResponseDto`
- `OrbPreviewActivationResponseDto`
- `OrbHeartbeatConfigResponseDto`
- `OrbFirmwareUploadResponseDto`

验收：

- 能 decode `PROTOCOL.md` 示例 JSON。

### W1.3 HTTP client

交付：

- `OrbHttpClient` 实现所有 API。
- Form encode。
- Multipart OTA。
- Timeout。
- HTTP error body logging。

验收：

- Mock server 验证每个 endpoint 的 method/path/body。

### W1.4 LUT mapper

交付：

- 默认 LUT。
- 插值 map。
- clamp。

验收：

- 单元测试覆盖端点补齐、乱序 points、超出范围。

### W1.5 AppStateStore

交付：

- `%APPDATA%\ORB\app_state.json`。
- async save。
- legacy migration。

验收：

- 缺文件返回默认状态。
- 坏 JSON 不崩并回默认。
- 保存再读取一致。

## M2：连接层

### W2.1 DeviceDiscoveryService

交付：

- DNS-SD browse/resolve。
- ServicesChanged snapshot。
- Stop cleanup。

验收：

- 服务新增/移除反映到 UI/debug log。

### W2.2 HeartbeatListenerService

交付：

- preferred/dynamic/unavailable status。
- HeartbeatReceived event。
- JSON decode error 不中断。

验收：

- 默认端口和动态端口两个场景通过。

### W2.3 ConnectionCoordinator

交付：

- 自动连接第一个服务。
- 心跳直连。
- reconnect 优先级。
- HTTP probe watchdog。
- heartbeat routing sync。

验收：

- 开机自动 online。
- 设备断电后 offline。
- 设备重启后自动恢复。

### W2.4 Manual IP

交付：

- 开发者设置中输入 IP/port。
- ping 成功后加载 state。

验收：

- DNS-SD 关闭时仍可连接。

## M3：指标和实时输出

### W3.1 WindowsSystemMetricsService

交付：

- CPU total。
- Memory。
- Network bps。
- Disk bps。
- Per-core best effort。
- Topology best effort。

验收：

- 空闲/负载状态变化合理。
- 首次采样 delta 项为 0，第二次开始有值。

### W3.2 Metric normalizer

交付：

- CPU/memory/rate normalization。
- fallback ranges。
- custom scale points。

验收：

- 单元测试覆盖网络/磁盘 piecewise。

### W3.3 OutputFrameScheduler

交付：

- metrics loop。
- ready gate。
- frame id。
- HTTP frame send。
- send failure logging。

验收：

- mock state + metrics 生成正确 frame。
- unknown/calibration/locate 时暂停。

## M4：首屏舞台

### W4.1 Stage layout

交付：

- Source + modules 横向排列。
- Mac 坐标常量迁移。
- 窗口 resize 重新布局。

验收：

- 760x520 和 1100x640 都不重叠。

### W4.2 Hotspots

交付：

- Source hotspot。
- Radiance tube hotspots。
- Balance gauge hotspots。
- Hover/active border。

验收：

- 点击目标区域准确。

### W4.3 Connection badge

交付：

- 状态圆点。
- 文案。
- 手动重连。
- tooltip。

验收：

- online/offline/not found 都显示正确。

### W4.4 Metric candidate panels

交付：

- Radiance tokens。
- Balance tokens。
- 点击绑定。
- 拖拽绑定。
- 已绑定 chip/label。
- 右键/拖回移除。

验收：

- CPU 多选和内存独占行为正确。
- Balance token 全局唯一。

### W4.5 Real-time simulation

交付：

- Radiance glow bars。
- Balance needle。
- Imported SVG display。
- Smoothing animation。

验收：

- 软件显示随 metrics 变化。

### W4.6 Module reorder

交付：

- 拖拽改变顺序。
- drop 后持久化。

验收：

- 重启后顺序保持。

## M5：注册和详情

### W5.1 Unknown device overlay

交付：

- 发现卡片。
- 注册面板。
- reset 面板。
- busy/notice/issue。

验收：

- `0x60` 新设备可注册。
- 旧地址设备可 reset 后继续注册。

### W5.2 Source detail

交付：

- 连接信息。
- 心跳摘要。
- 采样频率。
- metrics summary。
- 运动参数入口。

验收：

- 修改刷新周期生效并持久化。

### W5.3 Radiance detail

交付：

- 绑定摘要。
- 状态/地址。
- CPU core editor。
- debug panel。
- 寻找/校准/delete。

验收：

- 详情操作和舞台操作保持同步。

### W5.4 Balance detail

交付：

- metric picker。
- debug panel。
- 表盘 JSON/SVG 导入。
- 寻找/校准/delete。

验收：

- 导入后 scale points 和 SVG markup 持久化。

## M6：校准和运动参数

### W6.1 Calibration dialog

交付：

- Radiance target preview。
- Balance target preview。
- slider。
- 上一步/下一步/保存/取消。

验收：

- 通道预览 ACK 正确校验。
- 取消恢复实时输出。

### W6.2 Calibration save

交付：

- 保存 LUT 到固件。
- upsert 本地 LUT。
- apply state。

验收：

- 保存后 debug panel 显示 LUT 后 code。

### W6.3 Motion settings apply

交付：

- Draft editing。
- Radiance/Balance apply。
- ACK tolerance 校验。
- 成功提示。

验收：

- 固件返回参数和 UI 期望一致。

## M7：维护、托盘、OTA、本地化

### W7.1 Maintenance overlay

交付：

- 服务列表。
- 注册表快照。
- 运动参数。
- I2C debug。
- OTA。
- Manual IP。

验收：

- overlay 打开/关闭不影响输出 loop。

### W7.2 I2C debug

交付：

- 扫描。
- 当前地址 picker。
- 新地址 picker。
- 写入。

验收：

- mock 和硬件均可验证。

### W7.3 OTA

交付：

- 选择 BIN。
- 上传 progress。
- 成功后重连。

验收：

- 真实硬件 OTA 成功。

### W7.4 Tray

交付：

- 通知区图标。
- 左键打开。
- 右键菜单。
- 退出。

验收：

- 关闭主窗口后可从托盘恢复。

### W7.5 Localization

交付：

- zh-Hans/en/system。
- 主窗口和托盘菜单刷新。
- Windows 特有文案。

验收：

- 切语言不需要重启。

## M8：发布候选

### W8.1 Diagnostics

交付：

- 日志文件。
- 简单导出诊断信息。

验收：

- 用户可提供日志定位 discovery/metrics/OTA 问题。

### W8.2 Packaging

交付：

- Release build。
- 安装/卸载方案。
- README Windows 章节。

验收：

- 干净 Windows 11 机器可运行。

### W8.3 Full hardware regression

交付：

- 测试记录。
- 已知问题列表。

验收：

- `TEST_PLAN.md` 发布回归全部通过或有明确 waivers。

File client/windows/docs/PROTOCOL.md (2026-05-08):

# ESP32 Protocol

## 1. 常量

| 名称 | 值 |
| --- | --- |
| HTTP scheme | `http` |
| HTTP port | `80` |
| DNS-SD service type | `_orb._tcp.local.` |
| UDP heartbeat default port | `43981` |
| Heartbeat interval | `1500ms` |
| Max modules | `8` |
| Channels per module | `2` |
| DAC code range | `0...4095` |
| Fresh module address | `0x60` |
| Writable module addresses | `0x60...0x67` |

## 2. Naming

ESP32 JSON 使用 snake_case。Windows domain model 使用 PascalCase，但 DTO 必须显式映射 JSON 名称。

示例：

```csharp
public sealed record OrbDeviceStateDto(
    [property: JsonPropertyName("device_name")] string DeviceName,
    [property: JsonPropertyName("firmware_version")] string FirmwareVersion,
    [property: JsonPropertyName("state_revision")] int? StateRevision);
```

不要依赖全局 naming policy 猜字段，尤其是 `I2C`、`LUT`、`MAC`、`IP` 这类缩写字段。

## 3. Discovery

### 3.1 DNS-SD

浏览：

- Type：`_orb._tcp.local.`
- Instance：通常是 `ORB-XXXX`
- Port：`80`

TXT：

- `device`
- `fw`

解析结果进入 `DiscoveredService`：

```text
name: string
hostName: string?
port: int?
txt: dictionary<string,string>
```

连接时必须重新 resolve，不能长期信任旧 IP。

### 3.2 UDP Heartbeat

监听：

1. 优先绑定 UDP `43981`。
2. 如果失败，绑定动态端口。
3. 如果动态端口可用，连接后调用 `/api/v1/heartbeat/config`。

心跳 JSON：

```json
{
  "type": "heartbeat",
  "protocol_version": 1,
  "device_name": "ORB-1234",
  "firmware_version": "0.1.0",
  "ip": "192.168.1.120",
  "mac": "AA:BB:CC:DD:EE:FF",
  "port": 80,
  "sequence": 42,
  "state_revision": 8,
  "heartbeat_interval_ms": 1500,
  "default_port": 43981,
  "target_port": 43981,
  "configured_port": false,
  "delivery": "udp_broadcast",
  "uptime_ms": 123456,
  "registered_count": 2,
  "present_count": 2
}
```

兼容规则：

- `default_port`、`target_port`、`configured_port`、`delivery` 可以缺失。
- `receivedAt` 是客户端字段，不来自 JSON。
- 心跳按 `device_name` 或 `mac` 关联当前设备。没有当前设备时，任何 ORB 心跳都可触发加载状态。

## 4. HTTP Client

### 4.1 URL

```text
http://{endpoint.host}:{endpoint.port}{path}
```

`endpoint.port` 默认来自 DNS-SD 或 heartbeat 的 `port`。如果 state 内只有 IP，端口 fallback 为 `80`。

### 4.2 Timeouts

| 操作 | Timeout |
| --- | --- |
| ping/state/smoothing/register/delete/reset/i2c/calibration | `5s` |
| preview | 单次 `0.75...0.9s`，总重试窗口 `3s` |
| frame | `5s`，但失败只记录不弹窗 |
| OTA upload | `180s` |

### 4.3 Form Encoding

Mutating API 当前都用：

```text
Content-Type: application/x-www-form-urlencoded; charset=utf-8
```

字段按 key 排序不是协议要求，但 Mac 端这么做。Windows 可保持排序，方便测试。

百分号编码 allowlist：

```text
A-Z a-z 0-9 - . _ ~
```

## 5. Endpoints

### 5.1 GET `/api/v1/ping`

用途：

- 轻量探活。
- 获取 heartbeat routing 信息。
- 判断是否需要完整 state refresh。

响应：

```json
{
  "ok": true,
  "device_name": "ORB-1234",
  "firmware_version": "0.1.0",
  "ip": "192.168.1.120",
  "mac": "AA:BB:CC:DD:EE:FF",
  "port": 80,
  "state_revision": 8,
  "heartbeat_interval_ms": 1500,
  "heartbeat_default_port": 43981,
  "heartbeat_target_port": 43981,
  "heartbeat_configured_port": false,
  "heartbeat_delivery": "udp_broadcast"
}
```

### 5.2 POST `/api/v1/heartbeat/config`

请求：

```text
udp_port=43982
```

响应：

```json
{
  "ok": true,
  "heartbeat_default_port": 43981,
  "heartbeat_target_port": 43982,
  "heartbeat_configured_port": true,
  "heartbeat_delivery": "udp_broadcast"
}
```

ACK 校验：

- `ok == true`
- `heartbeat_target_port == listenerPort`
- `heartbeat_configured_port == true`

### 5.3 GET `/api/v1/state`

响应：

```json
{
  "device_name": "ORB-1234",
  "firmware_version": "0.1.0",
  "ip": "192.168.1.120",
  "mac": "AA:BB:CC:DD:EE:FF",
  "state_revision": 8,
  "heartbeat_interval_ms": 1500,
  "heartbeat_default_port": 43981,
  "heartbeat_target_port": 43981,
  "heartbeat_configured_port": false,
  "heartbeat_delivery": "udp_broadcast",
  "wifi_mode": "sta",
  "unknown_candidate_present": false,
  "detected_i2c_addresses": [96, 97],
  "unknown_i2c_addresses": [],
  "calibration_luts": [],
  "smoothing": {
    "radiance": {
      "settle_time_ms": 250,
      "a_max": 7.100,
      "v_max": 2.600,
      "jitter_frequency_hz": 2.500,
      "jitter_amplitude": 0.800,
      "jitter_dispersion": 0.320
    },
    "balance": {
      "settle_time_ms": 250,
      "a_max": 8.000,
      "v_max": 5.800,
      "jitter_frequency_hz": 0.000,
      "jitter_amplitude": 0.000,
      "jitter_dispersion": 0.250
    }
  },
  "modules": [
    {"id": 1, "registered": true, "present": true, "module_type": 1}
  ]
}
```

兼容：

- `unknown_candidate_present` 缺失时，用 `unknown_i2c_addresses` 是否为空推导。
- `calibration_luts` 缺失时保留本地已知 LUT。
- `smoothing` 缺失时使用默认参数。

### 5.4 POST `/api/v1/smoothing`

请求：

```text
module_type=1
settle_time_ms=350
a_max=7.100
v_max=2.600
jitter_frequency_hz=2.500
jitter_amplitude=0.800
jitter_dispersion=0.320
```

调用策略：

1. 先对 Radiance 调用。
2. 再对 Balance 调用。
3. 最终 state 必须同时校验 Radiance 和 Balance。

ACK 校验 tolerance：

- `settle_time_ms` 必须完全一致。
- 浮点字段误差 `<= 0.0015`。

### 5.5 POST `/api/v1/frame`

请求：

```text
frame_id=12
channels=1,0,2048;1,1,1024;2,0,3650
```

响应：

```json
{
  "ok": true,
  "frame_id": 12,
  "applied": 3
}
```

发送规则：

- 空 channels 不发送。
- 只有 ready 条件满足才发送。
- 请求失败只记日志，不弹用户 toast。
- `frame_id` app 运行期单调递增，重启后可从 0 重新开始。

### 5.6 POST `/api/v1/preview`

请求：

```text
mode=calibration
module_id=1
channel_index=0
target_code=2048
```

响应：

```json
{
  "ok": true,
  "preview_active": true,
  "mode": "calibration",
  "module_id": 1,
  "channel_index": 0,
  "target_code": 2048
}
```

ACK 必须逐字段校验。失败可重试条件：

- HTTP `>=500`
- timeout
- connection lost
- cannot connect
- DNS lookup failed
- not connected

不可重试：

- invalid URL
- invalid response
- JSON decode failed
- HTTP 4xx
- cancellation

### 5.7 POST `/api/v1/modules/register`

请求：

```text
module_type=1
id=1
address=96
```

注意：

- `module_type`：Radiance `1`，Balance `2`。
- `id=8` 在 UI 显示为 `ID 0`，协议仍传 `8`。
- `address` 是当前检测到的 I2C 地址十进制值，`0x60` 是 `96`。

成功响应完整 state。

### 5.8 POST `/api/v1/modules/delete`

请求：

```text
id=1
```

成功后 Windows 本地也要删除：

- `ModuleSetting`。
- 对应 `CalibrationLUT`。
- 舞台 layout slot。

### 5.9 POST `/api/v1/modules/reset`

请求：

```text
address=97
```

用途：把未知旧地址模块重置回 `0x60`。

限制：

- `address` 不能是 `0x60`。
- 目标 `0x60` 必须空闲。

### 5.10 POST `/api/v1/i2c/write_address`

请求：

```text
old_address=97
new_address=96
```

用途：开发者维护，不自动修改注册表。

### 5.11 POST `/api/v1/calibration/save`

请求：

```text
module_id=1
channel_index=0
points=0.0000:0.0000;0.2500:0.3000;0.5000:0.5200;0.7500:0.7600;1.0000:1.0000
updated_at_epoch=1778256000
```

规则：

- points 最少 2 点，最多 11 点。
- input/output 都是 `0...1` 浮点。
- 保存成功响应完整 state。

### 5.12 POST `/api/v1/firmware/upload`

请求：

- `multipart/form-data`
- field：`firmware`
- filename：用户选择的 `.bin`
- content type：`application/octet-stream`

响应：

```json
{
  "ok": true,
  "rebooting": true,
  "message": "固件上传成功，ESP32 正在重启。",
  "firmware_version": "0.1.0"
}
```

客户端行为：

1. 上传中禁止重复上传。
2. 成功后清空 selected file。
3. 清空 last contact / latest heartbeat。
4. 3 秒后自动 reconnect。

## 6. Address Rules

```text
ID 1 -> 0x61
ID 2 -> 0x62
ID 3 -> 0x63
ID 4 -> 0x64
ID 5 -> 0x65
ID 6 -> 0x66
ID 7 -> 0x67
ID 8 -> 0x60, UI label "0"
```

Windows helpers：

```text
SlotLabel(8) = "0"
AddressForModuleId(1...7) = 0x60 + id
AddressForModuleId(8) = 0x60
IdForAddress(0x61...0x67) = address - 0x60
IdForAddress(0x60) = 8
```

## 7. Error Mapping

常见固件 error：

| error | UI 文案建议 |
| --- | --- |
| `missing_*` | 客户端请求参数缺失，请升级客户端或反馈日志 |
| `invalid_*` | 请求参数不合法 |
| `module_not_registered` | 这个模块还未注册 |
| `module_not_present` | 模块当前离线，请检查供电和连接 |
| `slot_occupied` | 目标槽位已被占用 |
| `source_device_not_detected` | 当前地址没有检测到模块 |
| `target_address_busy` | 目标 I2C 地址已被占用 |
| `reserved_slot_not_allowed` | 前 7 个槽位未满，不能占用保留槽位 |
| `only_reserved_slot_available` | 前 7 个槽位已满，请使用 ID 0 |
| `address_rewrite_failed` | 模块改址失败，请断电重试 |
| `invalid_calibration_points` | LUT 点数量不足或格式不合法 |
| `firmware_upload_failed` | 固件上传失败，请确认 BIN 文件和网络 |

日志中保留 raw `error` 和 HTTP status，UI 文案做友好映射。

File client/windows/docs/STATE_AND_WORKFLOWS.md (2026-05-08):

# State And Workflows

## 1. Root State

根状态对应 Mac `AppModel`，但 Windows 实现时建议拆分。必须可观察的状态：

```text
AppLanguage
ConnectionStatus
DeviceState
DiscoveredServices
RefreshInterval
MotionDurationFactor
MotionDraftDurationFactor
SystemMetrics
SelectedModuleId
ShowingMaintenanceScreen
SelectedUnknownAddress
ActiveCalibration
PendingUnknownModuleType
PendingUnknownModuleId
UnknownDeviceNotice / Issue / IsBusy
ModuleActionNotice / Issue
I2CDebugSourceAddress / TargetAddress / IsScanning / IsWriting / Notice / Issue
SelectedFirmwarePath / IsUploadingFirmware / UploadNotice / UploadIssue
LocatingChannelKey
PendingCalibrationStartKey
LatestHeartbeat
HeartbeatListenerStatus
HeartbeatRoutingIssue
LocalNetworkAccessIssue
SmoothingActionIssue
MotionDraftProfiles
IsApplyingMotionSettings
MotionApplySuccessNotice
ReconnectStatusNotice
IsArrangingModules
```

内部状态：

```text
Layout
ModuleSettings
CalibrationLuts
ActiveEndpoint
HasBootstrapped
AutoConnectName
OutputFrameId
LastDeviceContactAt
LastAppliedStateRevision
LastLivenessProbeAt
HasLocalMotionDraftEdits
```

## 2. Persisted State

路径：

```text
%APPDATA%\ORB\app_state.json
```

Schema：

```json
{
  "layout": [
    {"id": "source", "position": 0, "moduleID": null, "kind": "source"},
    {"id": "module-1", "position": 1, "moduleID": 1, "kind": "module"}
  ],
  "moduleSettings": [
    {
      "moduleID": 1,
      "moduleType": 1,
      "channelBindings": [
        {
          "channelIndex": 0,
          "metric": {
            "kind": "cpuCoreAverage",
            "coreIndices": [0, 1],
            "userAssigned": false,
            "scalePoints": []
          }
        }
      ]
    }
  ],
  "refreshInterval": 0.5,
  "motionDurationFactor": 0.7,
  "calibrationLUTs": [],
  "appLanguage": "system"
}
```

兼容规则：

- `layout` 缺失或空：默认 `[source]`。
- `refreshInterval` 缺失：`0.5`。
- `motionDurationFactor` 缺失：`0.7`。
- `appLanguage` 缺失：`system`。
- `ModuleSetting.binding` legacy 单绑定：扩展为两个通道。
- `CalibrationLUT` 缺 `channelIndex`：视为 legacy shared LUT，迁移为通道 0 和 1。

保存时机：

- 语言改变。
- 刷新周期改变。
- 模块排序改变。
- 通道绑定改变。
- 校准 LUT 保存。
- state load 后完成 layout/settings merge。

## 3. Derived State

### 3.1 SourceIsOnline

```text
LastDeviceContactAt != null &&
Now - LastDeviceContactAt <= OfflineGraceWindow
```

### 3.2 HeartbeatGraceWindow

```text
interval = LatestHeartbeat.HeartbeatIntervalMs ?? DeviceState.HeartbeatIntervalMs ?? 1500
HeartbeatGraceWindow = max(interval / 1000 * 3.2, 2.5)
```

### 3.3 OfflineGraceWindow

```text
OfflineGraceWindow = HeartbeatGraceWindow + max(HeartbeatGraceWindow * 0.75, 3.0)
```

### 3.4 ConnectionStatus

```text
if SourceIsOnline -> Online
else if DeviceState != null || ActiveEndpoint != null || LatestHeartbeat != null -> Offline
else -> NotFound
```

## 4. Bootstrap Workflow

启动流程：

```mermaid
flowchart TD
  A["App starts"] --> B["Load app_state.json"]
  B --> C["Create ViewModels and Services"]
  C --> D["Start metrics/output loop"]
  D --> E["Start UDP heartbeat listener"]
  E --> F["Start heartbeat watchdog"]
  F --> G["Start DNS-SD discovery"]
  G --> H["Wait for service, heartbeat, or manual IP"]
```

Windows 没有 macOS 本地网络授权 primer，但需要准备防火墙说明：

- 首次 UDP 监听可能出现 Windows Defender Firewall 提示。
- UI 顶部可在检测到 UDP 不可用或一直收不到心跳时展示帮助文案。

## 5. Discovery And Connection Workflow

### 5.1 DNS-SD path

```text
DnsServiceBrowse finds service
-> ServicesChanged
-> if no ActiveEndpoint and no AutoConnectName
-> Resolve(serviceName)
-> ActiveEndpoint = resolved endpoint
-> FetchState(endpoint)
-> ApplyLoadedState(state)
```

### 5.2 Heartbeat path

```text
UDP heartbeat received
-> LatestHeartbeat = heartbeat
-> LastDeviceContactAt = heartbeat.ReceivedAt
-> If no current device, ActiveEndpoint = heartbeat.Endpoint
-> FetchState(heartbeat.Endpoint)
-> If state_revision changed later, delayed FetchState
```

### 5.3 Manual reconnect

优先级：

1. 如果当前设备名仍在 discovery list，按服务名 resolve。
2. 否则使用 latest heartbeat endpoint。
3. 否则使用 active endpoint。
4. 否则连接第一个 discovered service。

### 5.4 HTTP liveness probe

Watchdog 每 `500ms` 检查：

- 如果 UDP listener 不可用，允许 HTTP probe。
- 如果从未收到 heartbeat，但有 endpoint，超过 `max(heartbeatGraceWindow * 0.4, 1s)` probe。
- 如果有 heartbeat，但超过 `heartbeatGraceWindow` probe。
- 两次 probe 间隔至少 `max(min(heartbeatGraceWindow * 0.5, 2s), 1s)`。

Probe 成功：

- `ActiveEndpoint = endpoint`
- `LastDeviceContactAt = now`
- 应用 heartbeat route 字段。
- 如果 state revision 不同，加载完整 state。

## 6. Apply Loaded State

输入：

- `OrbDeviceState state`
- `preserveSelection`

步骤：

1. 清 `LocalNetworkAccessIssue`。
2. `ActiveEndpoint = (state.ip, previous port or 80)`。
3. `DeviceState = state`。
4. `CalibrationLuts = expanded(state.calibration_luts ?? local)`。
5. 更新 `LastDeviceContactAt`、`LastAppliedStateRevision`、`LastLivenessProbeAt`。
6. 清模块 action/smoothing issue。
7. `EnsureModuleSettings(state.registeredModules)`。
8. `MergeLayout(state.registeredModules)`。
9. 处理 unknown device selection。
10. 如果没有保留选择，选中第一个已注册模块；如果存在 unknown device，优先显示 unknown overlay。
11. `EnsureI2CDebugSelection()`。
12. `AutoConnectName = null`。
13. `UpdateConnectionStatus()`。
14. `SyncMotionDraftFromConfirmedState()`。
15. `PersistState()`。

## 7. Output Frame Workflow

Loop 周期：

```text
interval = max(RefreshInterval, 0.25)
```

步骤：

```text
Sample metrics
-> update SystemMetrics
-> BuildOutputFrameIfReady(snapshot)
-> if frame exists, POST /api/v1/frame
-> on success NoteDeviceContact(endpoint)
-> sleep interval
```

Ready 条件：

- `ActiveEndpoint != null`
- `DeviceState != null`
- `SourceIsOnline`
- `ActiveCalibration == null`
- `LocatingChannelKey == null`
- `PendingCalibrationStartKey == null`
- `DeviceState.UnknownI2CAddresses` 为空

Channel 规则：

- 只遍历 registered modules。
- 每个 module 取本地 `ModuleSetting`。
- 过滤 `MetricSourceKind.None`。
- CPU core / average 如果 coreIndices 为空，不发送。
- 归一化后用 LUT 转 `0...4095`。

归一化：

- `cpuTotal = totalPercent / 100`
- `cpuCoreAverage = selected core percent average / 100`
- `memoryUsage = used / total`
- `networkUp/down = custom scalePoints or fallback network ranges`
- `diskRead/write = custom scalePoints or fallback disk ranges`

Fallback network ranges：

```text
0..1 MiB/s       -> 0.00..0.30
1..10 MiB/s      -> 0.30..0.50
10..50 MiB/s     -> 0.50..0.70
50..100 MiB/s    -> 0.70..0.90
100..500 MiB/s   -> 0.90..1.00
```

Fallback disk ranges：

```text
0..1 MiB/s       -> 0.00..0.20
1..100 MiB/s     -> 0.20..0.60
100 MiB..1 GiB/s -> 0.60..0.80
1..5 GiB/s       -> 0.80..0.90
5..10 GiB/s      -> 0.90..1.00
```

## 8. Module Registration Workflow

### 8.1 Select unknown device

当 state 中 `unknown_i2c_addresses` 非空：

- UI 右侧展示“发现新设备”。
- 点击后默认 `pendingUnknownModuleType = Radiance`。
- `pendingUnknownModuleId = SuggestedRegistrationId(address)`。

### 8.2 Flow decision

```text
if available IDs 1...7 not empty:
  RegisterToNewAddress
else if slot 8 available:
  RegisterAsFinalSlot
else:
  if address == 0x60:
    RegisterAsFinalSlot
  else:
    ResetBeforeRegister
```

### 8.3 Register

条件：

- `SelectedUnknownAddress != null`
- `ActiveEndpoint != null`
- `ResolvedId in ValidRegistrationIds(address)`

步骤：

```text
IsPerformingUnknownDeviceAction = true
POST /api/v1/modules/register
ApplyLoadedState(state, preserveSelection=false)
SelectedUnknownAddress = null
SelectedModuleId = resolvedId
```

### 8.4 Reset old address

条件：

- `SelectedUnknownAddress != null`
- `SelectedUnknownAddress != 0x60`
- `ActiveEndpoint != null`

成功后：

- 如果 state 中看到 `0x60`，选中 `0x60` 并提示继续注册。
- 否则清选择并提示检查硬件。

## 9. Calibration Workflow

### 9.1 Begin

条件：

- `ActiveEndpoint != null`
- `SourceIsOnline`
- 当前未 locate。

步骤：

1. 取 existing LUT，缺失时使用默认 LUT。
2. 根据模块类型构建校准点。
3. `PendingCalibrationStartKey = "{moduleId}-{channelIndex}"`。
4. 调 `/api/v1/preview`，mode=`calibration`，target 为第一步 output code。
5. ACK 通过后打开 `ActiveCalibration`。
6. 启动 preview debounce。

Radiance 顺序：

```text
0.0, 0.5, 0.25, 1.0, 0.75
```

Balance 顺序：

- 使用当前 metric 的 `scalePoints.percent` 排序去重。
- 如果没有导入刻度，使用 `0.0...1.0` 每 `0.1`。

### 9.2 Preview

滑块更新：

```text
ActiveCalibration.CurrentStep.Output = clamp(value, 0, 1)
Debounce 90ms
POST /api/v1/preview
```

### 9.3 Save

步骤：

```text
Sort points by input
POST /api/v1/calibration/save
Upsert local LUT
Cancel preview task
ActiveCalibration = null
ApplyLoadedState(state, preserveSelection=true)
PersistState
SendCurrentOutputsIfPossible
```

### 9.4 Cancel

```text
Cancel preview/start tasks
ActiveCalibration = null
PendingCalibrationStartKey = null
ModuleActionIssue = null
SendCurrentOutputsIfPossible
```

## 10. Locate Workflow

点击“寻找”：

1. 取消校准启动 task。
2. `LocatingChannelKey = "{moduleId}-{channelIndex}"`。
3. `targetCode = round(0.5 * 4095)`。
4. 调 preview，mode=`locate`。
5. 120ms 后补发一次 preview。
6. 等 3 秒。
7. 清 locating key。
8. 恢复实时输出。

## 11. Motion Settings Workflow

Draft 和 confirmed：

- Confirmed 来自 `DeviceState.Smoothing`。
- Draft 来自 UI 本地编辑。
- 到位时间通过 `RefreshInterval * MotionDurationFactor` 转为 `settleTimeMs`。

Apply：

1. 如果没有 pending changes，不做。
2. 如果 source offline，不做并提示。
3. 调 smoothing Radiance。
4. 校验 ACK。
5. 调 smoothing Balance。
6. 同时校验 Radiance 和 Balance。
7. 成功后：
   - `MotionDurationFactor = desiredFactor`
   - `HasLocalMotionDraftEdits = false`
   - `ApplyLoadedState(finalState, preserveSelection=true)`
   - 展示成功提示 3 秒。

## 12. OTA Workflow

选择文件：

- 文件 dialog 允许 `.bin`，可以先用 all data 过滤，UI 文案提示 BIN。
- 保存 `SelectedFirmwarePath`。

上传：

1. 条件：`ActiveEndpoint != null`、`SourceIsOnline`、`SelectedFirmwarePath != null`。
2. `IsUploadingFirmware = true`。
3. multipart 上传。
4. 成功：
   - 清 selected file。
   - 展示 message。
   - `LastDeviceContactAt = null`
   - `LatestHeartbeat = null`
   - `UpdateConnectionStatus()`
   - 3 秒后 reconnect。
5. 失败：展示 OTA 失败文案。

## 13. Cancellation Ownership

| Task | Owner | Cancel when |
| --- | --- | --- |
| metrics/output loop | `OutputFrameScheduler` | app exit, refresh interval changed |
| heartbeat watchdog | `ConnectionCoordinator` | app exit |
| discovery | `DeviceDiscoveryService` | app exit |
| UDP listener | `HeartbeatListenerService` | app exit |
| calibration preview | `CalibrationWorkflow` | slider update, save, cancel, app exit |
| calibration start | `CalibrationWorkflow` | new locate/calibration, cancel, app exit |
| locate preview | `ModuleActionWorkflow` | new locate/calibration, app exit |
| OTA upload | `MaintenanceWorkflow` | app exit or explicit cancel if UI supports |
| notice dismiss | owning ViewModel | new notice, app exit |

## 14. Invariants

- 不在未知设备待处理时发送实时输出。
- 不在校准/寻找时发送实时输出。
- 保存本地状态不能阻塞 UI thread。
- `DeviceState.Modules` 是固件注册表事实源。
- `ModuleSettings` 是本地绑定事实源。
- `CalibrationLuts` 以固件返回为准，但固件缺字段时保留本地。
- UI 显示 ID 0 时，协议仍使用 module ID 8。

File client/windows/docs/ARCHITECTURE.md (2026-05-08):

# Architecture

## 1. 技术基线

- UI：WinUI 3。
- Runtime：.NET 10 LTS。
- Platform：Windows 11 desktop。
- Packaging：开发期先 unpackaged；发布期再决定 MSIX 或传统 installer。
- JSON：`System.Text.Json`。
- HTTP：`HttpClient`。
- UDP：`.NET Socket/UdpClient`，必要时下沉到 raw `Socket` 以设置端口复用。
- Native APIs：集中在 `Native/`，不要散落在 ViewModel。

## 2. 推荐目录

```text
client/windows/
  ORB.Windows.sln
  src/
    ORB.Windows/
      App.xaml
      MainWindow.xaml
      Assets/
        origin.png
        radiance.png
        balance.png
        orb_icon_set/
      Models/
      Services/
      ViewModels/
      Views/
      Controls/
      Calibration/
      Persistence/
      Native/
      Localization/
      Diagnostics/
  tests/
    ORB.Windows.Tests/
```

## 3. 层级边界

### 3.1 Views / Controls

职责：

- 只渲染状态和发出用户意图。
- 不直接调用 HTTP、UDP、Win32 API。
- 不直接读写文件。
- 可包含少量纯 UI 几何计算，例如舞台坐标、热点 rect、动画状态。

典型对象：

- `MainWindow`
- `ModuleStageView`
- `ConnectionBadge`
- `MetricCandidatePanel`
- `UnknownDeviceOverlay`
- `MaintenanceOverlay`
- `CalibrationDialog`
- `GaugeSvgView`

### 3.2 ViewModels

职责：

- 暴露 UI 可绑定状态。
- 调度 workflow。
- 统一处理 loading、notice、issue 文案。
- 持有 cancellation token / background loop lifecycle。

建议拆分：

- `AppViewModel`：根状态和 UI 导航。
- `ConnectionViewModel`：发现、心跳、连接状态。
- `ModuleStageViewModel`：舞台排序、热点选择、指标 token。
- `MaintenanceViewModel`：开发者设置、I2C、OTA。
- `CalibrationViewModel`：校准 dialog 状态。

### 3.3 Services

职责：

- 可 mock。
- 不依赖 WinUI 控件。
- 通过事件、channel 或 observable stream 汇报状态。
- 只返回 domain model 或 typed result。

核心服务：

```csharp
public interface IOrbHttpClient
{
    Task<OrbDeviceState> FetchStateAsync(OrbEndpoint endpoint, CancellationToken ct);
    Task<OrbPingResponse> PingAsync(OrbEndpoint endpoint, CancellationToken ct);
    Task<OrbHeartbeatConfigResponse> ConfigureHeartbeatAsync(OrbEndpoint endpoint, int listenerPort, CancellationToken ct);
    Task SendOutputsAsync(OrbEndpoint endpoint, OutputFrame frame, CancellationToken ct);
    Task<OrbPreviewActivationResponse> ActivatePreviewAsync(OrbEndpoint endpoint, OutputPreviewMode mode, int moduleId, int channelIndex, int targetCode, TimeSpan timeout, CancellationToken ct);
    Task<OrbDeviceState> RegisterModuleAsync(OrbEndpoint endpoint, ModuleType type, int id, int address, CancellationToken ct);
    Task<OrbDeviceState> DeleteModuleAsync(OrbEndpoint endpoint, int id, CancellationToken ct);
    Task<OrbDeviceState> ResetUnknownDeviceAsync(OrbEndpoint endpoint, int address, CancellationToken ct);
    Task<OrbDeviceState> WriteI2CAddressAsync(OrbEndpoint endpoint, int oldAddress, int newAddress, CancellationToken ct);
    Task<OrbDeviceState> SaveCalibrationLutAsync(OrbEndpoint endpoint, int moduleId, int channelIndex, IReadOnlyList<LutPoint> points, CancellationToken ct);
    Task<OrbFirmwareUploadResponse> UploadFirmwareAsync(OrbEndpoint endpoint, string filePath, IProgress<double>? progress, CancellationToken ct);
}
```

```csharp
public interface IDeviceDiscoveryService
{
    event EventHandler<IReadOnlyList<DiscoveredService>>? ServicesChanged;
    Task StartAsync(CancellationToken ct);
    Task StopAsync();
    Task<OrbEndpoint> ResolveAsync(string serviceName, CancellationToken ct);
}
```

```csharp
public interface IHeartbeatListenerService
{
    event EventHandler<OrbHeartbeat>? HeartbeatReceived;
    event EventHandler<HeartbeatListenerStatus>? StatusChanged;
    Task StartAsync(CancellationToken ct);
    Task StopAsync();
}
```

```csharp
public interface ISystemMetricsService
{
    Task<SystemMetricsSnapshot> SampleAsync(CancellationToken ct);
}
```

### 3.4 Native

职责：

- P/Invoke declarations。
- Win32 handle lifetime。
- Native error code 转 typed exception。
- API-specific DTO 不上浮到 ViewModel。

目录建议：

```text
Native/
  Win32DnsSd.cs
  Win32IpHelper.cs
  Win32Memory.cs
  Win32Processor.cs
  Win32Pdh.cs
  Win32ShellNotifyIcon.cs
```

## 4. Runtime 线程模型

### 4.1 UI thread

只做：

- 更新 observable properties。
- 响应用户操作。
- 创建/关闭 WinUI dialog。

禁止：

- 同步等待 HTTP/UDP。
- 高速指标采样。
- 文件上传读大文件。

### 4.2 Background loops

Loop 列表：

- Metrics/output loop：默认 `0.5s`，最小 `0.25s`。
- Heartbeat watchdog：`0.5s` 检查一次是否需要 HTTP probe。
- Discovery listener：由 DNS-SD callback 驱动。
- UDP listener：阻塞接收，收到后 marshal 到 UI dispatcher。

每个 loop 必须由 owner 持有 `CancellationTokenSource`：

- `AppViewModel` 负责 app lifetime。
- `ConnectionCoordinator` 负责 discovery/heartbeat/watchdog。
- `OutputFrameScheduler` 负责 metrics/output。
- `CalibrationWorkflow` 负责 preview debounce。

### 4.3 Dispatcher 规则

- Service callback 进入 ViewModel 前使用 `DispatcherQueue.TryEnqueue`。
- ViewModel 内状态变更必须在 UI thread。
- Service 内部不依赖 `DispatcherQueue`。

## 5. Dependency Injection

建议使用轻量 DI 容器：

- `IOrbHttpClient -> OrbHttpClient`
- `IDeviceDiscoveryService -> Win32DnsSdDiscoveryService`
- `IHeartbeatListenerService -> UdpHeartbeatListenerService`
- `ISystemMetricsService -> WindowsSystemMetricsService`
- `IAppStateStore -> AppStateStore`
- `IFileDialogService -> FileDialogService`
- `ITrayService -> ShellTrayService`
- `ILogger<T>` 或项目内 `IDiagnosticsLogger`

开发期可先手写 service locator，但接口边界要先定住，方便测试。

## 6. 错误模型

统一 domain exception：

- `OrbHttpException(statusCode, endpoint, body)`
- `OrbProtocolException(message, body)`
- `OrbDiscoveryException(kind, message)`
- `OrbHeartbeatException(kind, message)`
- `OrbSystemMetricsException(metric, message)`
- `OrbFileException(path, message)`

UI 文案不直接展示 raw exception：

- HTTP 4xx/5xx 映射成“设备拒绝请求 / 当前模块离线 / 地址冲突”等。
- 网络失败映射成“无法连接主控，请确认 Windows 与 ORB 在同一局域网”。
- UDP 被防火墙拦截时提示允许专用网络入站。

## 7. 日志和诊断

第一版至少记录到：

- Debug output。
- `%LOCALAPPDATA%\ORB\logs\orb-windows.log`，按大小滚动。

日志等级：

- `Info`：启动、发现设备、连接、状态刷新、输出帧每 10 帧摘要。
- `Warn`：心跳丢失、HTTP probe 失败、指标采样 fallback。
- `Error`：HTTP API 错误、OTA 失败、native API 初始化失败。

不要记录：

- Wi-Fi 密码。
- 用户文件完整内容。
- 大量每帧 channels 明细。

## 8. 资源策略

直接复用 Mac 资源：

- `origin.png`
- `radiance.png`
- `balance.png`
- `orb_icon_set/*`

复制到 Windows app `Assets/` 后通过 project file 打包。

后续可把产品图提升到 `assets/client/` 公共目录，但第一版不要因为资源重组阻塞工程。

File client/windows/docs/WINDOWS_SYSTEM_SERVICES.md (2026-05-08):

# Windows System Services

## 1. System Metrics Service

目标输出：

```text
SystemMetricsSnapshot
  SampledAt
  TotalCPUUsagePercent
  CPUCoreLoads[]
  MemoryUsedBytes
  MemoryTotalBytes
  NetworkReceiveBytesPerSecond
  NetworkSendBytesPerSecond
  DiskReadBytesPerSecond
  DiskWriteBytesPerSecond
  GPUUsagePercent?
```

所有采样失败都应该降级为 `0` 或 `null`，并记录 warn，不应导致输出 loop 崩溃。

### 1.1 CPU total

首选：

- Win32 `GetSystemTimes`。
- 记录 idle/kernel/user ticks。
- delta 公式：

```text
busy = (kernelDelta + userDelta) - idleDelta
total = kernelDelta + userDelta
usage = busy / total * 100
```

注意：

- `kernel` 包含 idle，所以要减去 idle。
- 第一次采样返回 `0`，等待下一次 delta。

### 1.2 CPU per core

需要 M0 spike 决定最终实现。推荐优先级：

1. PDH English counters：`\\Processor Information(*)\\% Processor Utility` 或 `\\Processor Information(*)\\% Processor Time`。
2. 如果 PDH instance 排序和 core ID 映射不稳定，再评估 native processor performance information。
3. 如果 per-core 失败，返回空数组，UI fallback 到总 CPU。

要求：

- core index 稳定从 `0` 开始。
- 不把 `_Total` 作为一个 core。
- 多 processor group 机器要排序稳定，例如按 group, number。
- 采样周期小于 PDH 可靠周期时，可缓存上一笔 per-core 数据。

### 1.3 CPU topology

首选：

- `GetSystemCpuSetInformation`。
- 使用 `EfficiencyClass` 区分：
  - 低 efficiency class：performance。
  - 高 efficiency class：efficiency。

由于厂商和 Windows 版本差异，分类规则必须能降级：

- 如果所有 core `EfficiencyClass` 相同，全部标为 `unknown` 或全部 performance。
- 如果 API 失败，按逻辑核心数生成 `unknown`。

UI token：

- 如果存在 performance core，显示“大核平均”。
- 如果存在 efficiency core，显示“小核平均”。
- 如果都 unknown，只显示每个 CPU 核心和内存。

### 1.4 Memory

Win32 API：

- `GlobalMemoryStatusEx`

字段：

```text
MemoryTotalBytes = ullTotalPhys
MemoryUsedBytes = ullTotalPhys - ullAvailPhys
MemoryUsagePercent = MemoryUsedBytes / MemoryTotalBytes * 100
```

### 1.5 Network

Win32 API：

- `GetIfTable2`

字段：

- `MIB_IF_ROW2.InOctets`
- `MIB_IF_ROW2.OutOctets`

过滤建议：

- `OperStatus == IfOperStatusUp`
- 排除 loopback。
- 排除 tunnel。
- 优先保留 hardware interface。
- 虚拟网卡第一版可以计入总量；如用户反馈偏高，再加“忽略虚拟网卡”设置。

delta：

```text
receiveBps = max(current.InOctets - previous.InOctets, 0) / elapsedSeconds
sendBps = max(current.OutOctets - previous.OutOctets, 0) / elapsedSeconds
```

接口变化：

- 按 interface LUID 或 index 聚合。
- 如果接口集合变化，仍对总量做 delta；若 current < previous，返回 0 并重置 previous。

### 1.6 Disk

第一版建议：

- PDH English counters。

Counters：

```text
\\PhysicalDisk(_Total)\\Disk Read Bytes/sec
\\PhysicalDisk(_Total)\\Disk Write Bytes/sec
```

原因：

- 与 Mac IOKit 总磁盘吞吐心智一致。
- 可直接获得 bytes/sec，不需要自己处理每块磁盘累计计数。

注意：

- 使用 `PdhAddEnglishCounterW`，不要用本地化 counter name。
- 初始化 PDH query 后第一次采样可能为 0，下一次才可信。
- 如果 PDH 不可用，返回 0 并记录 warn。

### 1.7 GPU

第一版：

- 保留字段 `GPUUsagePercent = null`。
- 不在 UI 中暴露 GPU token。

后续候选：

- PDH GPU Engine counters。
- DXGI。
- 厂商 SDK。

## 2. Device Discovery Service

### 2.1 首选：Win32 DNS-SD

API：

- `DnsServiceBrowse`
- `DnsServiceResolve`

浏览目标：

```text
_orb._tcp.local.
```

输出：

```text
DiscoveredService
  Name
  HostName
  Port
  Txt
```

实现要求：

- Browse callback 不直接改 UI state，先进入 service 内部集合，再向 ViewModel 发布 snapshot。
- Resolve 可按需触发，也可发现后自动 resolve。
- 服务消失时移除缓存 endpoint。
- 解析失败不清空其他服务。

### 2.2 Fallback

必须存在：

1. UDP heartbeat direct connect：只要收到心跳就能连接。
2. Manual IP：开发者设置中输入 IP/port。
3. 嵌入式 mDNS fallback：M0 spike 后决定是否实现。

Manual IP 规则：

- 默认 port `80`。
- 输入后先 `GET /api/v1/ping`，成功再加载 state。
- 成功连接后可把 endpoint 记入本次运行内存，不必持久化到本地状态。

## 3. UDP Heartbeat Listener

绑定策略：

1. 尝试 `0.0.0.0:43981`。
2. 设置端口复用，避免重启时短时间占用问题。
3. 如果失败，绑定 `0.0.0.0:0`，由系统分配动态端口。
4. 向 UI 发布：
   - `PreferredUdp`
   - `DynamicUdp`
   - `Unavailable`

状态字段：

```text
HeartbeatListenerStatus
  Mode
  LocalPort
  Message
```

收到数据：

- UTF-8 decode。
- JSON decode 为 `OrbHeartbeat`。
- 设置 `ReceivedAt = DateTimeOffset.Now`。
- 发布到 `ConnectionCoordinator`。

异常：

- JSON decode 失败：记录 warn，继续监听。
- socket receive 失败：记录 warn，重启 listener 或转 unavailable。
- 防火墙导致无数据：通常没有异常，只能通过长时间收不到心跳 + HTTP probe 成功推断。

## 4. Heartbeat Routing

当 `HeartbeatListenerStatus.IsAvailable` 且 `DeviceState` 表明固件支持 heartbeat routing：

```text
if DeviceState.HeartbeatTargetPort != LocalPort || DeviceState.HeartbeatConfiguredPort != true:
  POST /api/v1/heartbeat/config udp_port=LocalPort
```

失败时：

- 不影响 HTTP 控制。
- UI 展示非阻塞问题：`UDP 心跳端口同步失败...`
- Watchdog 继续用 HTTP probe。

## 5. Windows Defender Firewall UX

可能触发时机：

- UDP listener 开始监听入站。
- DNS-SD/mDNS multicast。

UI 文案建议：

```text
Windows 可能正在拦截 ORB 的局域网心跳。请在 Windows 安全中心或防火墙弹窗中允许 ORB 访问“专用网络”。如果你暂时不允许，ORB 仍会尝试通过 HTTP 保持连接，但状态刷新可能变慢。
```

不要引导用户允许公共网络，默认建议专用网络。

## 6. Tray Service

WinUI 3 没有内建通知区图标，封装 Win32：

- `Shell_NotifyIcon`
- hidden window message callback
- context menu

菜单：

```text
连接状态：已连接/未连接/离线
打开主窗口
开发者设置
退出
```

行为：

- 左键单击：显示主窗口。
- 右键：context menu。
- 双击：同左键。
- 退出：取消所有 background loops，然后关闭 app。

## 7. File Dialog Service

需要三类选择：

- OTA `.bin`。
- Gauge JSON。
- Gauge SVG。

建议：

- 用 Windows App SDK / Win32 file picker，并封装为 `IFileDialogService`。
- 返回 path，不在 ViewModel 里直接 new dialog。
- 读取 SVG 后保存 markup 到 `MetricBinding.DialSVGMarkup`。
- JSON/SVG 导入失败要区分：
  - 文件不可读。
  - JSON 格式不合法。
  - JSON 无有效 tick。
  - SVG 找不到或不可读。

Gauge JSON 解析：

```text
state.majorTicks[]
  valueText
  unitText
  percent
```

单位换算：

```text
B/byte/bytes -> value
K/KB -> value * 1024
M/MB -> value * 1024^2
G/GB -> value * 1024^3
```

SVG 自动查找顺序：

1. 和 JSON 同名 `.svg`。
2. 当前 metric 对应文件：
   - `网速上行.svg`
   - `网速下行.svg`
   - `硬盘读取.svg`
   - `硬盘写入.svg`
3. 同目录唯一 `.svg`。
4. 弹文件选择。

## 8. App Data Paths

Roaming state：

```text
%APPDATA%\ORB\app_state.json
```

Local logs/cache：

```text
%LOCALAPPDATA%\ORB\logs\
%LOCALAPPDATA%\ORB\cache\
```

不要把用户选择的固件文件复制到 app data。

## 9. Native API Spike Checklist

M0 需要实际验证：

- DNS-SD 能否发现 ESP32 的 `_orb._tcp.local.`。
- 默认 UDP 43981 被占用时，动态端口 + `/heartbeat/config` 是否稳定。
- Windows Defender Firewall 首次弹窗文案和触发点。
- PDH per-core counter 的 instance 排序。
- PDH disk counter 在中文 Windows 上是否能通过 English counter 打开。
- `GetIfTable2` 是否把虚拟网卡导致的吞吐计入过高。
- `GetSystemCpuSetInformation` 在 Intel/AMD/ARM 混合架构上的分类表现。

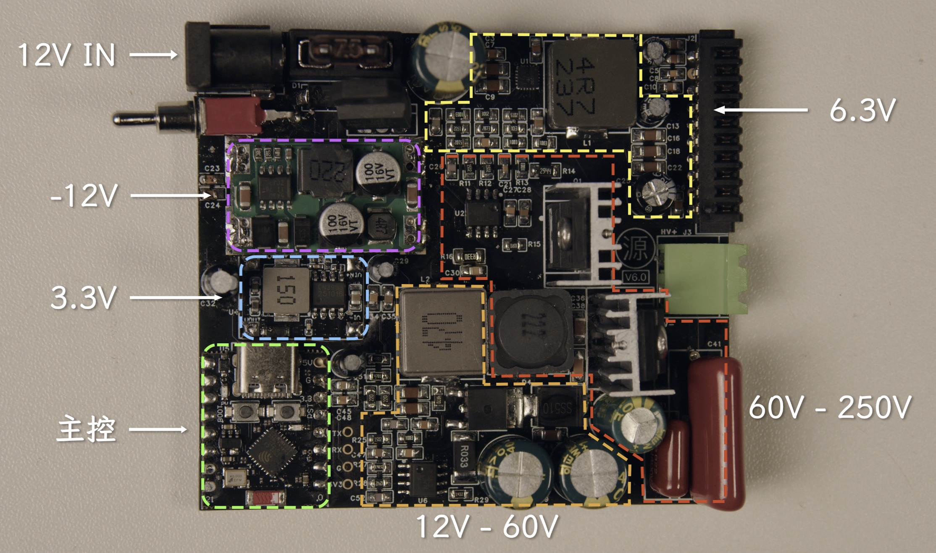
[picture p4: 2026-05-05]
assets/origin_pcb.jpeg

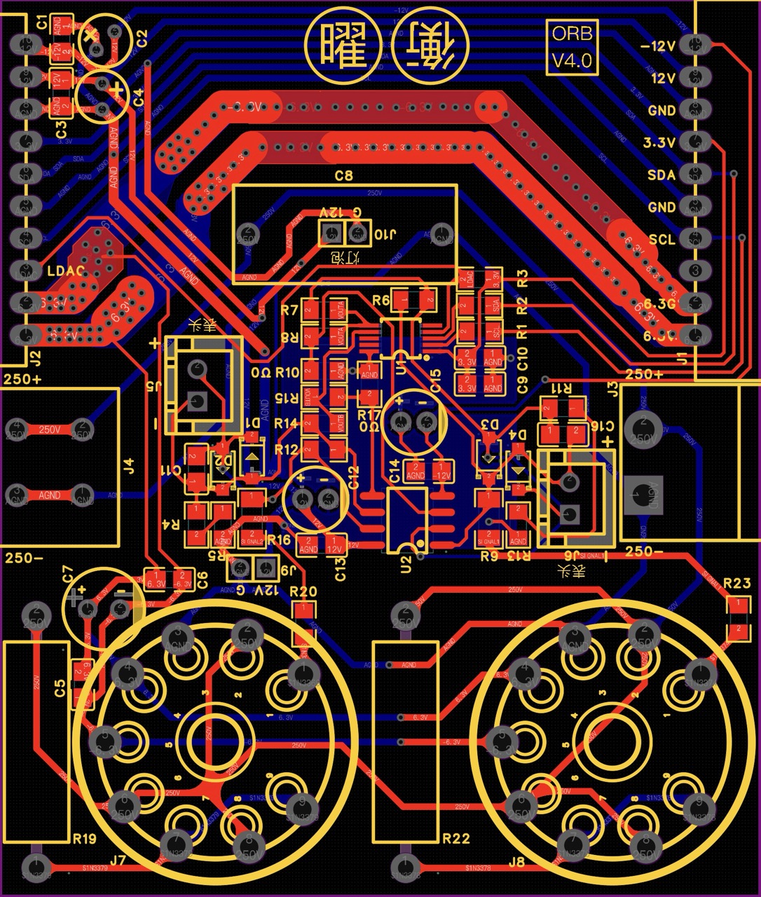
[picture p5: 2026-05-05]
assets/radiance_pcb.jpeg

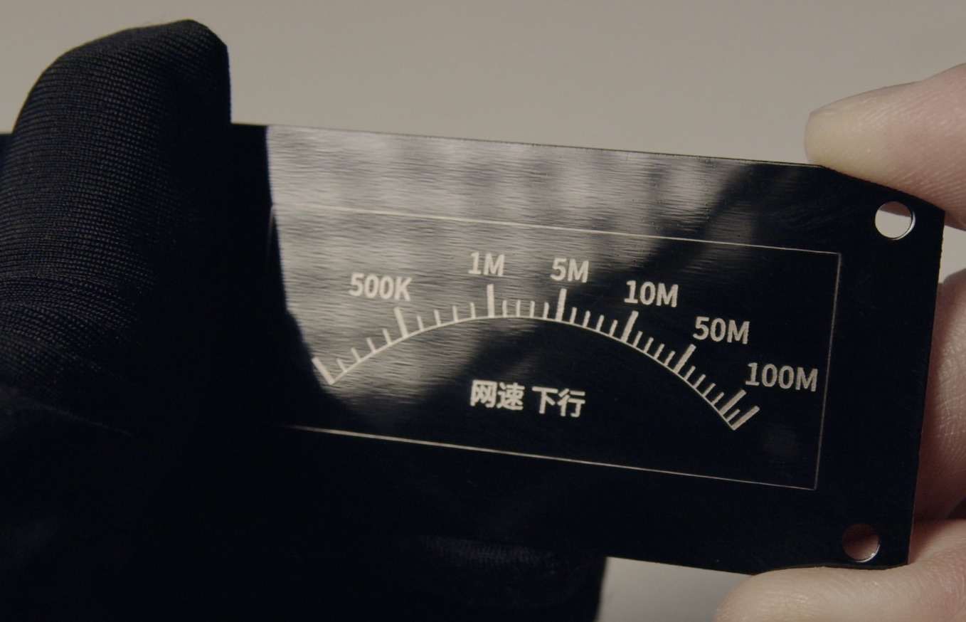
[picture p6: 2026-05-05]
assets/gauge.jpeg

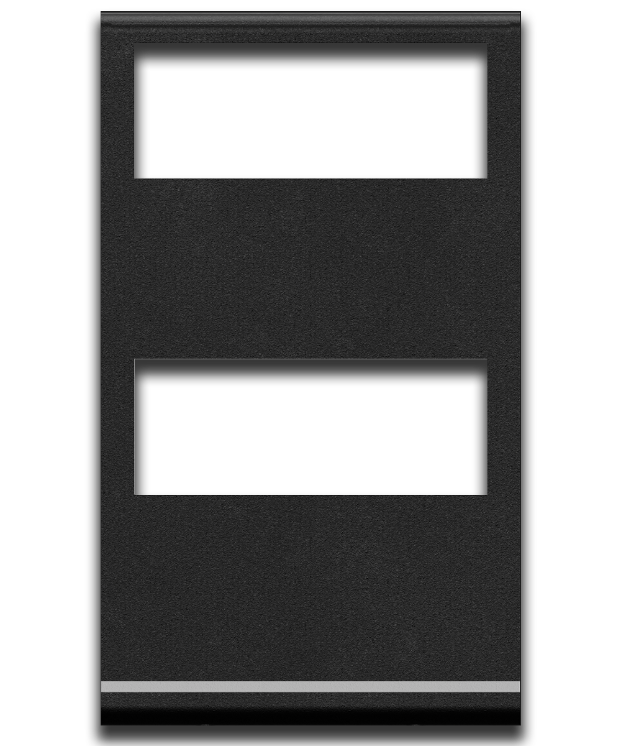
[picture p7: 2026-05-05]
client/macos/ORB/ORB/resources/balance.png

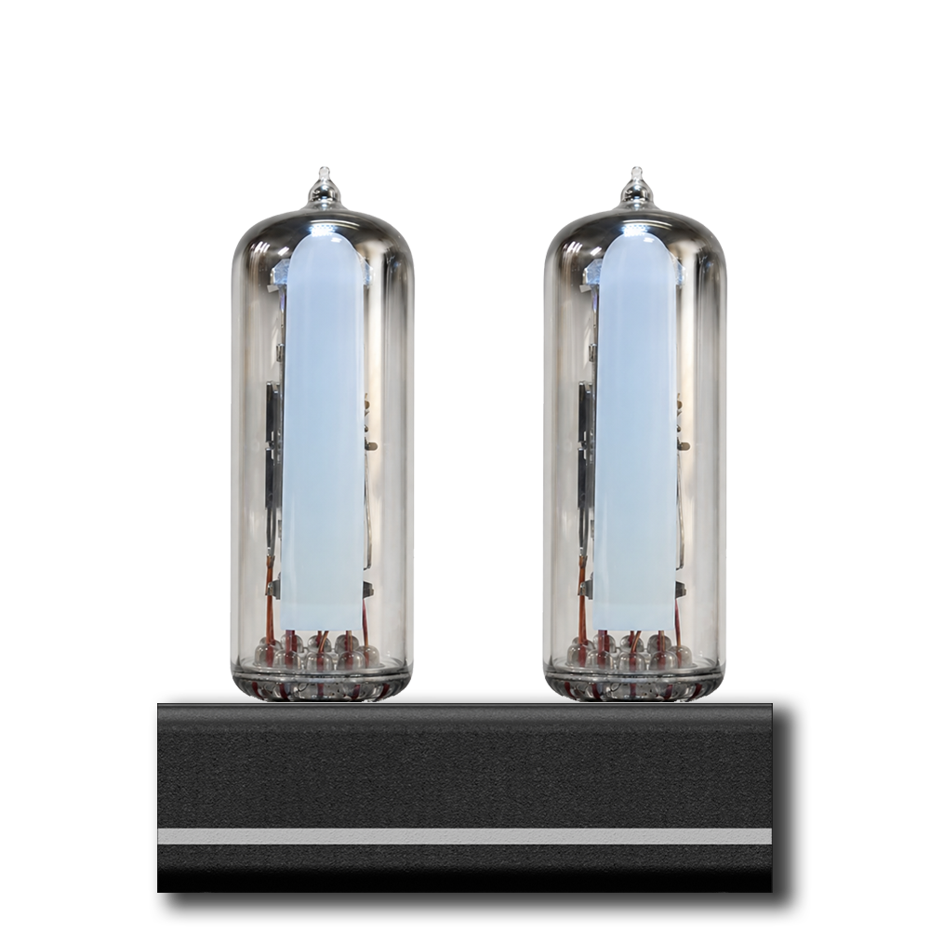
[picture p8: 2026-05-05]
client/macos/ORB/ORB/resources/radiance.png

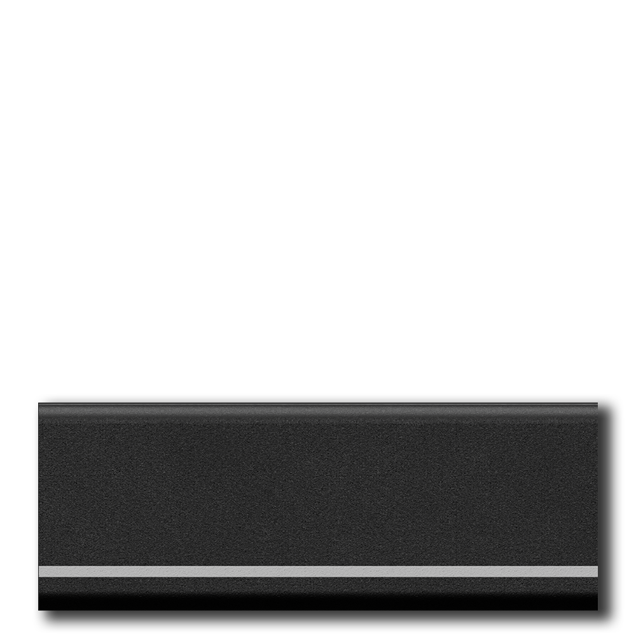
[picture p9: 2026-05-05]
client/macos/ORB/ORB/resources/origin.png

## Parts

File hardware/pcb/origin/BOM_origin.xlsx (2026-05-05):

No. | Quantity | Comment | Designator | Footprint | Value | Manufacturer Part | Manufacturer | Supplier Part | Supplier | 备注
1 | 8 | 1uF | C1,C8,C12,C15,C23,C28,C34,C45 | C0805 | 1uF | CL21B105KBFNNNE | SAMSUNG(三星) | C28323 | LCSC
2 | 11 | 100nF | C2,C3,C5,C10,C11,C24,C26,C27,C35,C43,C48 | C0805 | 100nF | FCC0805B104K500DT | FOJAN(富捷) | C5137467 | LCSC
3 | 3 | 22uF | C4,C29,C51 | CAP-TH_BD4.0-P1.50-D0.8-FD | 22uF | KS226M025C07RR0VH2FP0 | Chengx(承兴) | C43840 | LCSC
4 | 1 | 2200uF | C6 | CAP-TH_BD10.0-P5.00-D0.6-FD | 2200uF | ERA16V2200M10X20 | JIERR(捷而瑞) | C49256793 | LCSC
5 | 7 | 22uF | C7,C9,C16,C18,C22,C39,C40 | C1206 | 22uF | CL31A226KAHNNNE | SAMSUNG(三星) | C12891 | LCSC
6 | 1 | 100uF | C13 | CAP-TH_BD5.0-P2.00-D0.5-FD-A | 100uF | ERG16V100M5X11 | JIERR(捷而瑞) | C47344171 | LCSC
7 | 1 | 220nF | C14 | C0805 | 220nF | CL21B224KBFNNNE | SAMSUNG(三星) | C5378 | LCSC
8 | 1 | 10nF | C19 | C0805 | 10nF | GRM2195C1H103FA01D | muRata(村田) | C441760 | LCSC
9 | 3 | 100pF | C20,C42,C52 | C0805 | 100pF | CL21C101JBANNNC | SAMSUNG(三星) | C1790 | LCSC
10 | 1 | 330pF | C21 | C0805 | 330pF | CC0805JRNPO9BN331 | YAGEO(国巨) | C107116 | LCSC
11 | 1 | 220uF | C25 | CAP-TH_BD6.3-P2.50-D0.5-FD | 220uF | ERG16V220M6X7 | JIERR(捷而瑞) | C47344172 | LCSC
12 | 2 | 220pF | C30,C46 | C0805 | 220pF | CC0805KRX7R9BB221 | YAGEO(国巨) | C107145 | LCSC
13 | 1 | 100nF | C31 | CAP-TH_L13.0-W5.0-P10.00-D0.6 | 100nF | MPS104K2H4AA420MA1 | JOEY(久亦) | C4355397 | LCSC | 耐压400V
14 | 1 | 10uF | C32 | CAP-TH_BD5.0-P2.00-D0.5-FD-A | 10uF | ERG25V10M5X11 | JIERR(捷而瑞) | C47344176 | LCSC
15 | 2 | 1uF | C36,C44 | C1206 | 1uF | CL31B105KCHNNNE | SAMSUNG(三星) | C13832 | LCSC | 耐压100V
16 | 1 | 10uF | C37 | CAP-TH_BD8.0-P3.50-D0.5-FD | 10uF | ERA400V10M8X12 | JIERR(捷而瑞) | C49256828 | LCSC | 耐压400V
17 | 1 | 100nF | C38 | C1206 | 100nF | 1206B104K101NT | FH(风华) | C110255 | LCSC | 耐压100V
18 | 1 | 1uF | C41 | CAP-TH_L22.0-W7.8-P20.00-D0.8 | 1uF | MPP105J2G20AJ22810 | KNSCHA(科尼盛) | C506841 | LCSC | 耐压400V
19 | 1 | 3.3nF | C47 | C0805 | 3.3nF | CC0805JKNPO0BN332 | YAGEO(国巨) | C527199 | LCSC
20 | 2 | 47uF | C49,C50 | CAP-TH_BD10.0-P5.00-D1.0-FD | 47uF | RC100M470LO10*12TH-2A1E | BERYL(绿宝石) | C365777 | LCSC | 耐压100V
21 | 1 | SMBJ15A | D1 | SMB_L4.6-W3.6-LS5.3-RD |  | SMBJ15A | Littelfuse(美国力特) | C83846 | LCSC
22 | 1 | MBR2045CT | D2 | TO-220AB-3_L10.4-W4.6-P2.54-T |  | MBR2045CT | MDD(辰达半导体) | C173461 | LCSC | 防反接二极管，有把握可不装
23 | 1 | SS5150C | D4 | SMC_L6.9-W5.9-LS7.9-RD |  | SS5150C | MDD(辰达半导体) | C65015 | LCSC
24 | 1 | STTH8R06D | D5 | TO-220-2_L10.2-W4.5-P5.08-L |  | STTH8R06D | ST(意法半导体) | C283269 | LCSC | 建议装散热片
25 | 1 | FUSE 7.5A | F1 | FUSE-TH_4P-L16.0-W6.7 |  | FUSE 7.5A | XFCN(兴飞) | C19727305 | LCSC | 汽车保险丝，5-8A均可
26 | 1 | DC-005-A200 | J1 | DC-IN-TH_DC-005-A200 |  | DC-005-A200 | XUNPU(讯普) | C720557 | LCSC | 建议5.5x2.5，3A起
27 | 1 | 10P刀片式连接器 | J2 | 10P刀片电池座 90度母 P2.5 |  |  |  |  |  | https://item.taobao.com/item.htm?id=923725335194&skuId=6168434019160
28 | 1 | WJ2EDGRC-5.08-02P-14-00A | J3 | CONN-TH_2P-P5.08_WJ2EDGRC-5.08-2P |  | WJ2EDGRC-5.08-02P-14-00A | KANGNEX(康奈克斯电气) | C3697 | LCSC | https://item.taobao.com/item.htm?id=816212714660&skuId=5812540746317
29 | 1 | 4.7uH | L1 | IND-SMD_L13.45-W12.6 | 4.7uH | FXL1360-4R7-M | cjiang(长江微电) | C526021 | LCSC | https://detail.tmall.com/item.htm?from=orderBuyAgain&id=961298214536&openSku=true&skuId=5896297645660
30 | 1 | 47uH | L2 | IND-SMD_L13.5-W12.8_ZEMS1265 | 47uH | ZEMS1265-470M | ZE(增益) | C41415658 | LCSC | https://detail.tmall.com/item.htm?id=961968113416&skuId=6062127191910
31 | 1 | 2.2mH | L3 | IND-SMD_L12.0-W12.0_YPRH120X | 2.2mH | YPRH1207-222M | YJYCOIN(益嘉源) | C19632965 | LCSC | https://item.taobao.com/item.htm?id=610669881087&skuId=4296428056305
32 | 1 | FQPF8N60C | Q1 | TO-220F-3_L10.2-W4.9-P2.54-L |  | FQPF8N60C | onsemi(安森美) | C2703 | LCSC | 必须装散热片
33 | 1 | FQD13N10LTM | Q2 | TO-252-3L_L6.6-W6.1-P4.60-LS9.5-BR |  | FQD13N10LTM | TECH PUBLIC(台舟) | C5350889 | LCSC
34 | 5 | 100kΩ | R1,R8,R9,R13,R24 | R0805 | 100kΩ | 0805W8F1003T5E | UNI-ROYAL(厚声) | C149504 | LCSC
35 | 1 | 30kΩ | R2 | R0805 | 30kΩ | 0805W8F3002T5E | UNI-ROYAL(厚声) | C17621 | LCSC
36 | 2 | 51kΩ | R3,R10 | R0805 | 51kΩ | 0805W8F5102T5E | UNI-ROYAL(厚声) | C17737 | LCSC
37 | 4 | 15kΩ | R4,R11,R12,R25 | R0805 | 15kΩ | RC0805FR-0715KL | YAGEO(国巨) | C114559 | LCSC
38 | 1 | 287kΩ | R5 | R0805 | 287kΩ | 0805W8F2873T5E | UNI-ROYAL(厚声) | C17598 | LCSC
39 | 1 | 10kΩ | R6 | R0805 | 10kΩ | 0805W8F1002T5E | UNI-ROYAL(厚声) | C17414 | LCSC
40 | 1 | 2.94MΩ | R14 | R1206 | 2.94MΩ | 1206W4F2944T5E | UNI-ROYAL(厚声) | C422547 | LCSC | 也可用3MΩ
41 | 1 | 10Ω | R15 | R0805_NEW | 10Ω | 0805W8F100JT5E | UNI-ROYAL(厚声) | C17415 | LCSC
42 | 1 | 330mΩ | R16 | R1206 | 330mΩ | HoYH1206-1W-330mR-1% | Milliohm(毫欧) | C2932844 | LCSC
43 | 2 | 4.7kΩ | R18,R19 | R0805 | 4.7kΩ | SFR10EZPF4701 | ROHM(罗姆) | C2105721 | LCSC
44 | 2 | 22Ω | R20,R21 | R0805 | 22Ω | AF0805FR-0722RL | YAGEO(国巨) | C2105132 | LCSC
45 | 1 | 4.7Ω | R22 | R0805 | 4.7Ω | 0805W8J047JT5E | UNI-ROYAL(厚声) | C25316 | LCSC
46 | 1 | 470kΩ | R23 | R2512 | 470kΩ | 25121WF4703T4E | UNI-ROYAL(厚声) | C55559 | LCSC
47 | 1 | 33mΩ | R26 | R2512 | 33mΩ | 25121WJ033LT4E | UNI-ROYAL(厚声) | C55739 | LCSC
48 | 1 | 576kΩ | R27 | R0805 | 576kΩ | 0805W8F5763T5E | UNI-ROYAL(厚声) | C17760 | LCSC
49 | 1 | 12.4kΩ | R28 | R0805 | 12.4kΩ | 0805W8F1242T5E | UNI-ROYAL(厚声) | C30908 | LCSC
50 | 1 | 56.2kΩ | R29 | R0805 | 56.2kΩ | 0805W8F5622T5E | UNI-ROYAL(厚声) | C17751 | LCSC
51 | 1 | ST-0-102-C04-N008-RS | SW1 | SW-TH_ST-0-102-C04-N008-RS |  | ST-0-102-C04-N008-RS | YUEN FUNG(源丰) | C1788491 | LCSC | https://item.taobao.com/item.htm?id=592452009879&skuId=4252048687831
52 | 1 | TPS568230RJER | U1 | QFN-20_L3.0-W3.0-P0.45-BL-EP1.0 |  | TPS568230RJER | TI(德州仪器) | C2878938 | LCSC | 建议贴散热片
53 | 2 | LM3478MAX/NOPB | U2,U6 | SOIC-8_L4.9-W3.9-P1.27-LS6.0-BL |  | LM3478MAX/NOPB | TI(德州仪器) | C115907 | LCSC
54 | 1 | -12反相模块 | U3 | -12V反相模块 |  |  |  |  |  | https://detail.tmall.com/item.htm?id=693916248140&skuId=4931022721595
55 | 1 | 3.3V降压模块 | U4 | 3.3V降压模块 |  |  |  |  |  | https://item.taobao.com/item.htm?id=866588693436&skuId=5693691061668
56 | 1 | ESP32C3-SuperMini | U5 | COMM-SMD_16P-L22.5-W18.0-P2.54-TL |  | ESP32C3-SuperMini |  | C9900147397 | LCSC | https://item.taobao.com/item.htm?id=965597504812&skuId=6070989050837
 |  | 机身风扇 |  | 20*20*6 |  |  |  |  |  | https://item.taobao.com/item.htm?id=955833420608&skuId=5879167337701
 |  | TO-220散热片 |  | 16*15*10孔高13 |  |  |  |  |  | https://item.taobao.com/item.htm?id=667014720601&skuId=4807340672362

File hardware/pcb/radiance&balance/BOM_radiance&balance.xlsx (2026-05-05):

No. | Quantity | Comment | Designator | Footprint | Value | Manufacturer Part | Manufacturer | Supplier Part | Supplier | 备注
1 | 8 | 100nF | C1,C3,C5,C10,C11,C13,C14,C16 | C0805 | 100nF | FCC0805B104K500DT | FOJAN(富捷) | C5137467 | LCSC
2 | 2 | 47uF | C2,C4 | CAP-TH_BD4.0-P2.00-D0.5-FD | 47uF | 04EC2022 | KNSCHA(科尼盛) | C2760861 | LCSC
3 | 1 | 1uF | C6 | C0805 | 1uF | CL21B105KBFNNNE | SAMSUNG(三星) | C28323 | LCSC
4 | 1 | 220uF | C7 | CAP-TH_BD6.3-P2.50-D0.5-FD | 220uF | ERG16V220M6X7 | JIERR(捷而瑞) | C47344172 | LCSC
5 | 1 | 22nF | C8 | CAP-TH_L17.0-W7.5-P15.00-D0.8 | 22nF | PS223J3A1503 | KYET(科雅) | C478442 | LCSC | 耐压400V
6 | 1 | 10uF | C9 | C0805 | 10uF | CGA0805X5R106K250MT | HRE(芯声) | C6119887 | LCSC
7 | 2 | 10uF | C12,C15 | CAP-TH_BD5.0-P2.00-D0.5-FD-A | 10uF | ERG25V10M5X11 | JIERR(捷而瑞) | C47344176 | LCSC
8 | 4 | 1N4148W | D1,D2,D3,D4 | SOD-123_L2.7-W1.6-LS3.7-FD |  | 1N4148W | R+O(宏嘉诚) | C7420318 | LCSC
9 | 1 | BUS OUT | J1 | 10P刀片电池座 90度母 P2.5 |  |  |  |  |  | https://item.taobao.com/item.htm?id=923725335194&skuId=6168434019160
10 | 1 | BUS IN | J2 | 10P刀片电池座 90度公 P2.5 |  |  |  |  |  | https://item.taobao.com/item.htm?id=923725335194&skuId=6168434019161
11 | 1 | WJ2EDGRC-5.08-02P-14-00A | J3 | CONN-TH_2P-P5.08_WJ2EDGRC-5.08-2P |  | WJ2EDGRC-5.08-02P-14-00A | KANGNEX(康奈克斯电气) | C3697 | LCSC | https://item.taobao.com/item.htm?id=816212714660&skuId=5812540746317
12 | 1 | KF2EDGA-5.08-2P | J4 | CONN-TH_4P-P5.08_KF2EDGA-5.08-2P |  | KF2EDGA-5.08-2P | KEFA(科发) | C6394123 | LCSC | https://item.taobao.com/item.htm?id=816212714660&skuId=5812540746317
13 | 2 | HX-XH2.54-2PZZ | J5,J6 | CONN-TH_2P-P2.50_HX-2.54MM-2P-ZZ-MS |  | HX-XH2.54-2PZZ | hanxia(韩下) | C42391660 | LCSC | XH2.54母座，也可不装，直接焊线
14 | 2 | 6E2-G | J7,J8 | 9 PIN TUBE SOCKET |  | 6E2-G |  |  |  | https://item.taobao.com/item.htm?id=9729199698&skuId=3431182249943
15 | 4 | 22Ω | R1,R2,R4,R11 | R0805 | 22Ω | 0805W8F220JT5E | UNI-ROYAL(厚声) | C17561 | LCSC
16 | 5 | 10kΩ | R3,R7,R8,R14,R15 | R0805 | 10kΩ | 0805W8F1002T5E | UNI-ROYAL(厚声) | C17414 | LCSC
17 | 2 | 390Ω | R5,R13 | R0805 | 390Ω | 0805W8F3900T5E | UNI-ROYAL(厚声) | C17655 | LCSC
18 | 2 | 36kΩ | R6,R12 | R0805 | 36kΩ | 0805W8F3602T5E | UNI-ROYAL(厚声) | C4360 | LCSC
19 | 2 | 220Ω | R9,R16 | R1206 | 220Ω | 1206W4J0221T5E | UNI-ROYAL(厚声) | C25363 | LCSC
20 | 2 | 390kΩ | R19,R22 | RES-TH_BD5.0-L15.5-P19.50-D0.8 | 390kΩ | RSF200JB-73-390K | YAGEO(国巨) | C1365654 | LCSC | 金属膜电阻，2W
21 | 2 | 1MΩ | R20,R23 | R0805 | 1MΩ | 0805W8J0105T5E | UNI-ROYAL(厚声) | C26115 | LCSC
22 | 1 | MCP4728-E/UN | U1 | MSOP-10_L3.0-W3.0-P0.50-LS5.0-TL |  | MCP4728-E/UN | MICROCHIP(美国微芯) | C108207 | LCSC
23 | 1 | OPA2171AIDR | U2 | SOIC-8_L5.0-W4.0-P1.27-LS6.0-BL |  | OPA2171AIDR | TI(德州仪器) | C40904 | LCSC
 |  | 电流表 |  |  |  |  |  |  |  | https://item.taobao.com/item.htm?id=566347146133&skuId=3760656682192

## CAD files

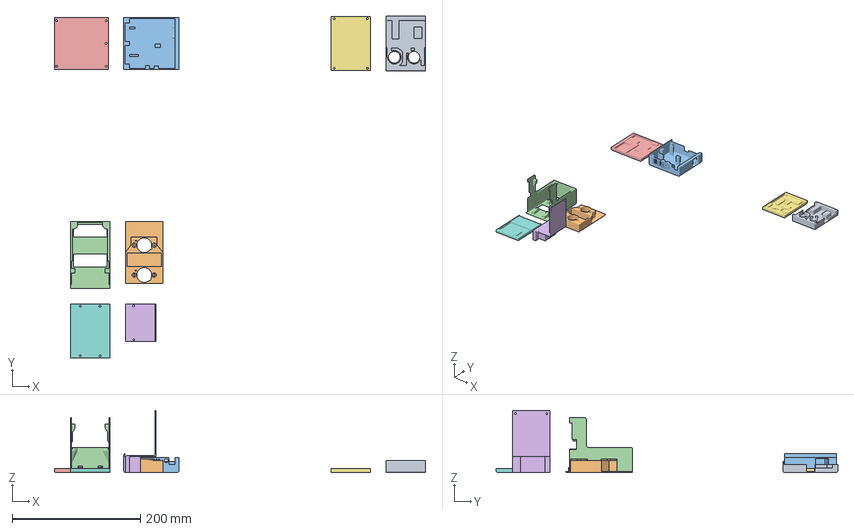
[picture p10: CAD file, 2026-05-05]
hardware/case/ORB.3mf
579.0 x 533.3 x 97.0 mm
曜_B
衡_B_B_A
源_A x 2
衡_A
衡_B_B_B
曜_A
衡_B_A

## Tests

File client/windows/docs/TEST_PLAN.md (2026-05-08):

# Test Plan

## 1. 测试层级

```text
Unit tests
  Pure models, mapping, normalization, LUT, encoding

Integration tests
  Mock HTTP server, mock UDP heartbeat, fake metrics source

Manual hardware tests
  Real ESP32 + real modules + Windows 11 machines

Release regression
  Fresh install, upgrade, firewall, OTA, packaging
```

## 2. Unit Tests

### 2.1 Address mapping

Cases：

- `AddressForModuleId(1) == 0x61`
- `AddressForModuleId(7) == 0x67`
- `AddressForModuleId(8) == 0x60`
- `SlotLabel(8) == "0"`
- invalid ID returns null/throws typed validation error。

### 2.2 JSON decode

Fixtures：

- `state_full.json`
- `state_missing_optional_fields.json`
- `heartbeat_full.json`
- `heartbeat_legacy_no_route.json`

Assert：

- snake_case fields map correctly。
- missing `unknown_candidate_present` is derived from unknown addresses。
- missing smoothing uses defaults。
- missing calibration LUTs does not clear local state unexpectedly。

### 2.3 Form encode

Cases：

- `/frame` channels format。
- `/preview` fields。
- `/calibration/save` points format with 4 decimals。
- percent encoding of special characters。

### 2.4 LUT mapper

Cases：

- no LUT：`0 -> 0`，`1 -> 4095`，`0.5 -> 2048`。
- unordered points sorted before interpolation。
- missing endpoint inserts `(0,0)` and `(1,1)`。
- output clamped to `0...4095`。
- duplicate input points do not divide by zero。

### 2.5 Metric normalization

Cases：

- total CPU clamp。
- core average with selected cores。
- core selection empty returns not-send。
- memory `used/total`。
- network fallback ranges。
- disk fallback ranges。
- custom scale points。
- custom scale points beyond max clamp to last percent。

### 2.6 Ready gate

Cases：

- no endpoint -> no frame。
- offline -> no frame。
- active calibration -> no frame。
- locating -> no frame。
- unknown devices -> no frame。
- metric none -> no channel。
- CPU metric with empty core list -> no channel。

### 2.7 Persistence

Cases：

- no file -> defaults。
- bad JSON -> defaults + log。
- legacy `binding` -> two channelBindings。
- legacy shared LUT -> channel 0 and 1。
- save/read roundtrip。

## 3. Integration Tests

### 3.1 Mock HTTP server

模拟 endpoints：

- `/api/v1/ping`
- `/api/v1/state`
- `/api/v1/heartbeat/config`
- `/api/v1/frame`
- `/api/v1/preview`
- `/api/v1/modules/register`
- `/api/v1/modules/delete`
- `/api/v1/modules/reset`
- `/api/v1/i2c/write_address`
- `/api/v1/calibration/save`
- `/api/v1/firmware/upload`

Assert：

- method/path/content-type 正确。
- form body 正确。
- timeout 和 cancellation 正确。
- 4xx/5xx 映射到 typed exception。

### 3.2 UDP heartbeat broadcaster

Cases：

- preferred port receives heartbeat。
- dynamic port receives heartbeat after preferred occupied。
- invalid JSON ignored。
- heartbeat state revision change triggers delayed state refresh。

### 3.3 Connection coordinator

使用 fake discovery + fake heartbeat + mock HTTP：

- discovery first connect。
- heartbeat first connect。
- reconnect prefers current service name。
- HTTP probe recovers online status。
- HTTP probe failure leaves offline/not found correctly。

### 3.4 Output loop

使用 fake metrics：

- 每 tick 生成 frame。
- refresh interval changed restarts loop。
- frame send success notes device contact。
- frame send failure only logs。

### 3.5 Calibration workflow

Mock preview endpoint：

- ACK exact match opens dialog。
- ACK mismatched mode/module/channel/target fails。
- retry on transient timeout。
- save LUT calls calibration endpoint and upserts local LUT。

### 3.6 OTA workflow

Mock upload：

- multipart contains firmware field。
- progress advances。
- success clears file and schedules reconnect。
- failure preserves selected file and shows issue。

## 4. Manual Hardware Tests

### 4.1 Test matrix

至少覆盖：

- Windows 11 x64 desktop/laptop。
- Windows 11 arm64，如果可获得设备。
- 中文系统。
- 英文系统。
- 普通家用路由器。
- 至少一个存在虚拟网卡的环境。

### 4.2 Discovery and connection

Steps：

1. ORB 已接入 Wi-Fi。
2. 打开 Windows 客户端。
3. 等待自动发现。

Expected：

- 设备进入 online。
- 服务列表显示 `ORB-XXXX`。
- 心跳摘要更新。
- IP/MAC/固件版本正确。

### 4.3 Firewall scenarios

Scenario A：允许专用网络。

- 收到 UDP 心跳。
- 不依赖频繁 HTTP probe。

Scenario B：拒绝或阻断 UDP。

- HTTP probe 仍可保持基本在线。
- UI 有可理解提示。
- 操作不崩。

### 4.4 Metrics output

Steps：

- 绑定曜通道到 CPU core average。
- 运行 CPU load。
- 绑定曜通道到 memory。
- 增加内存压力。
- 绑定衡通道到 network up/down。
- 下载/上传文件。
- 绑定衡通道到 disk read/write。
- 拷贝大文件。

Expected：

- 硬件显示和软件模拟都随指标变化。
- debug panel 值合理。

### 4.5 Module registration

Steps：

1. 只接一个新模块，地址 `0x60`。
2. 选择曜，注册到 ID 1。
3. 断电换另一个新模块。
4. 选择衡，注册到 ID 2。

Expected：

- 注册成功后模块显示在线。
- I2C 地址符合规则。
- 本地 binding 默认值正确。

### 4.6 Reset old unknown device

Steps：

1. 制造一个不在注册表但地址为 `0x61...0x67` 的模块。
2. 客户端显示 reset 流程。
3. reset。
4. 继续注册。

Expected：

- reset 后看到 `0x60`。
- 可注册。

### 4.7 Locate

Steps：

- 对每个通道点击寻找。

Expected：

- 只有目标通道亮/动。
- 3 秒后恢复实时输出。

### 4.8 Calibration

Radiance：

- 按 `0%, 50%, 25%, 100%, 75%` 完成。
- 保存 LUT。
- 重启客户端。

Expected：

- LUT 状态保留。
- 输出使用 LUT 后 code。

Balance：

- 导入 gauge JSON/SVG。
- 按导入刻度校准。
- 保存 LUT。

Expected：

- 校准目标显示导入 SVG。
- 指针位置和表盘刻度一致。

### 4.9 Motion settings

Steps：

- 修改到位时间。
- 修改曜/衡响应力度、最大速度、抖动参数。
- 应用。

Expected：

- 固件返回参数一致。
- 舞台模拟和硬件运动变化明显。
- 重启客户端后参数从设备同步。

### 4.10 I2C debug

Steps：

- 扫描现有 I2C。
- 选择地址。
- 改写到空闲地址。

Expected：

- 扫描显示正确地址。
- 改址成功后新地址出现。
- 注册表不被自动修改。

### 4.11 OTA

Steps：

- 选择 `.bin`。
- 上传。
- 等设备重启。

Expected：

- 上传成功提示。
- 设备重启期间 offline。
- 之后自动 reconnect。

## 5. Release Regression

必须通过：

- 干净 Windows 11 安装后首次启动。
- 无硬件启动。
- 有硬件自动连接。
- 托盘打开/关闭/退出。
- 中英文切换。
- app_state 写入和重启恢复。
- 日志文件生成。
- 卸载后不影响用户自己保存的固件文件。

## 6. Test Artifacts

建议新增：

```text
tests/ORB.Windows.Tests/Fixtures/
  state_full.json
  state_missing_optional_fields.json
  heartbeat_full.json
  heartbeat_legacy_no_route.json
  gauge_export.json
  gauge.svg
```

硬件回归记录：

```text
client/windows/docs/test-runs/YYYY-MM-DD-rcN.md
```

记录内容：

- Windows 版本。
- 机器架构。
- 网络环境。
- ORB 固件版本。
- 模块数量和类型。
- 通过/失败项。
- 日志片段。

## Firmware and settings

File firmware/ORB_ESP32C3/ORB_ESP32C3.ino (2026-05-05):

#include <Arduino.h>
#include <WiFi.h>
#include <Wire.h>

#include "src/ApiServer.h"
#include "src/BonjourService.h"
#include "src/CalibrationStore.h"
#include "src/Config.h"
#include "src/HeartbeatService.h"
#include "src/MCP4728Driver.h"
#include "src/ModuleBus.h"
#include "src/RegistryStore.h"
#include "src/SmoothingEngine.h"
#include "src/WiFiProvisioning.h"

namespace {
orb::RegistryStore registryStore;
orb::CalibrationStore calibrationStore;
orb::MCP4728Driver dacDriver;
orb::ModuleBus moduleBus;
orb::SmoothingEngine smoothingEngine;
orb::WiFiProvisioning wifiProvisioning;
orb::BonjourService bonjourService;
orb::HeartbeatService heartbeatService;
orb::ApiServer apiServer(registryStore, calibrationStore, moduleBus, dacDriver, smoothingEngine, heartbeatService, wifiProvisioning);

wl_status_t lastWiFiStatus = WL_IDLE_STATUS;

const char* wifiStatusLabel(wl_status_t status) {
  switch (status) {
    case WL_NO_SHIELD:
      return "无 Wi-Fi 模块";
    case WL_IDLE_STATUS:
      return "空闲";
    case WL_NO_SSID_AVAIL:
      return "找不到 SSID";
    case WL_SCAN_COMPLETED:
      return "扫描完成";
    case WL_CONNECTED:
      return "已连接";
    case WL_CONNECT_FAILED:
      return "连接失败";
    case WL_CONNECTION_LOST:
      return "连接丢失";
    case WL_DISCONNECTED:
      return "已断开";
    default:
      return "未知状态";
  }
}
}

void setup() {
  Serial.begin(115200);
  delay(200);
  Serial.println();
  Serial.println("ORB ESP32C3 正在启动...");

  Wire.begin(orb::kPinI2CSDA, orb::kPinI2CSCL, orb::kI2CFrequencyHz);

  registryStore.begin();
  calibrationStore.begin();
  dacDriver.begin(Wire);
  moduleBus.begin(Wire);
  smoothingEngine.begin(dacDriver);
  wifiProvisioning.begin();
  heartbeatService.begin();
  const bool shouldStartBonjour = !wifiProvisioning.isAccessPointMode() && WiFi.status() == WL_CONNECTED;
  const bool bonjourStarted =
      shouldStartBonjour ? bonjourService.begin(wifiProvisioning.deviceName(), orb::kWebPort) : false;
  if (!shouldStartBonjour) {
    Serial.println("[mDNS] 跳过 Bonjour：当前处于配网模式或尚未接入局域网");
  }
  apiServer.begin();

  moduleBus.refreshPresence(registryStore);
  lastWiFiStatus = WiFi.status();

  Serial.printf("设备名称：%s\n", wifiProvisioning.deviceName().c_str());
  Serial.printf("当前网络地址：http://%s/\n", wifiProvisioning.currentIP().c_str());
  Serial.printf("Bonjour 地址：http://%s.local/\n", wifiProvisioning.deviceName().c_str());
  Serial.printf("Bonjour 广播：%s\n", bonjourStarted ? "成功" : "失败");
  Serial.printf("当前 Wi-Fi 状态：%s (%d)\n", wifiStatusLabel(lastWiFiStatus), static_cast<int>(lastWiFiStatus));
}

void loop() {
  wifiProvisioning.handleDNS();
  if (wifiProvisioning.promoteStationConnectionIfNeeded()) {
    const bool bonjourRestarted = bonjourService.begin(wifiProvisioning.deviceName(), orb::kWebPort);
    Serial.printf("[mDNS] 切换到局域网后重新广播：%s\n", bonjourRestarted ? "成功" : "失败");
    Serial.printf("[HTTP] 当前可访问地址：http://%s/\n", wifiProvisioning.currentIP().c_str());
  }
  heartbeatService.handle(wifiProvisioning, registryStore);
  apiServer.handleClient();
  smoothingEngine.tick(registryStore);

  const wl_status_t currentStatus = WiFi.status();
  if (currentStatus != lastWiFiStatus) {
    lastWiFiStatus = currentStatus;
    Serial.printf("[WiFi] 站点状态变更：%s (%d)\n", wifiStatusLabel(currentStatus), static_cast<int>(currentStatus));
    if (currentStatus == WL_CONNECTED) {
      Serial.printf("[WiFi] 已连上路由器，IP=%s，MAC=%s\n",
                    WiFi.localIP().toString().c_str(),
                    WiFi.macAddress().c_str());
    }
  }
}

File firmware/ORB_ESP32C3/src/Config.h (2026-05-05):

#pragma once

#include <Arduino.h>

namespace orb {

static constexpr uint8_t kPinI2CSDA = 8;
static constexpr uint8_t kPinI2CSCL = 9;
static constexpr uint8_t kPinMcpLdac = 10;

static constexpr uint32_t kI2CFrequencyHz = 100000;
static constexpr uint16_t kWebPort = 80;
static constexpr uint16_t kHeartbeatPort = 43981;
static constexpr size_t kMaxModules = 8;
static constexpr size_t kChannelsPerModule = 2;
static constexpr uint8_t kUnknownModuleAddress = 0x60;

static constexpr uint32_t kPresenceScanIntervalMs = 1000;
static constexpr uint32_t kSmoothingTickMs = 10;
static constexpr uint32_t kHeartbeatIntervalMs = 1500;
static constexpr char kFirmwareVersion[] = "0.1.0";
static constexpr uint16_t kDefaultSettleTimeMs = 250;
static constexpr float kDefaultRadianceAMax = 7.1f;
static constexpr float kDefaultRadianceVMax = 2.6f;
static constexpr float kDefaultBalanceAMax = 8.0f;
static constexpr float kDefaultBalanceVMax = 5.8f;
static constexpr float kDefaultRadianceJitterFrequencyHz = 2.5f;
static constexpr float kDefaultRadianceJitterAmplitude = 0.8f;
static constexpr float kDefaultRadianceJitterDispersion = 0.32f;
static constexpr float kDefaultBalanceJitterFrequencyHz = 0.0f;
static constexpr float kDefaultBalanceJitterAmplitude = 0.0f;
static constexpr float kDefaultBalanceJitterDispersion = 0.25f;
static constexpr uint32_t kWiFiConnectTimeoutMs = 15000;

static constexpr char kAccessPointSSID[] = "ORB-SETUP";
static constexpr uint8_t kAccessPointChannel = 1;
static constexpr char kRegistryNamespace[] = "orb-reg";
static constexpr char kWiFiNamespace[] = "orb-wifi";
static constexpr char kSmoothingNamespace[] = "orb-smooth";
static constexpr char kCalibrationNamespace[] = "orb-lut";

inline String makeDefaultDeviceName() {
  uint64_t mac = ESP.getEfuseMac();
  char buffer[16];
  snprintf(buffer, sizeof(buffer), "ORB-%04X", static_cast<unsigned>(mac & 0xFFFF));
  return String(buffer);
}

}  // namespace orb

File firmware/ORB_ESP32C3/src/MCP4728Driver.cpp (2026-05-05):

#include "MCP4728Driver.h"

#include "Config.h"

namespace orb {

namespace {
bool multiWriteOne(TwoWire& wire, uint8_t address, uint8_t channel, uint16_t code) {
  channel &= 0x03;
  code &= 0x0FFF;

  const uint8_t dac1 = (channel >> 1) & 0x01;
  const uint8_t dac0 = channel & 0x01;
  const uint8_t command = static_cast<uint8_t>(0b01000000 | (dac1 << 2) | (dac0 << 1));
  const uint8_t byte3 = static_cast<uint8_t>((code >> 8) & 0x0F);
  const uint8_t byte4 = static_cast<uint8_t>(code & 0xFF);

  wire.beginTransmission(address);
  wire.write(command);
  wire.write(byte3);
  wire.write(byte4);
  return wire.endTransmission(true) == 0;
}

constexpr int kI2CRewriteDelayUs = 8;

void sdaLow() {
  pinMode(kPinI2CSDA, OUTPUT);
  digitalWrite(kPinI2CSDA, LOW);
}

void sdaRelease() {
  pinMode(kPinI2CSDA, INPUT);
}

void sclLow() {
  pinMode(kPinI2CSCL, OUTPUT);
  digitalWrite(kPinI2CSCL, LOW);
}

void sclRelease() {
  pinMode(kPinI2CSCL, INPUT);
}

bool sdaRead() {
  pinMode(kPinI2CSDA, INPUT);
  return digitalRead(kPinI2CSDA);
}

void ldacHigh() {
  digitalWrite(kPinMcpLdac, HIGH);
}

void ldacLow() {
  digitalWrite(kPinMcpLdac, LOW);
}

void i2cDelay() {
  delayMicroseconds(kI2CRewriteDelayUs);
}

void bbInitBus() {
  sdaRelease();
  sclRelease();
  i2cDelay();
}

void bbStart() {
  sdaRelease();
  sclRelease();
  i2cDelay();
  sdaLow();
  i2cDelay();
  sclLow();
  i2cDelay();
}

void bbStop() {
  sdaLow();
  i2cDelay();
  sclRelease();
  i2cDelay();
  sdaRelease();
  i2cDelay();
}

bool bbWriteBit(bool bitVal) {
  if (bitVal) {
    sdaRelease();
  } else {
    sdaLow();
  }

  i2cDelay();
  sclRelease();
  i2cDelay();
  sclLow();
  i2cDelay();
  return true;
}

bool bbReadAck() {
  sdaRelease();
  i2cDelay();
  sclRelease();
  i2cDelay();
  const bool ack = !sdaRead();
  sclLow();
  i2cDelay();
  return ack;
}

bool bbWriteByteNormal(uint8_t data) {
  for (int i = 7; i >= 0; --i) {
    bbWriteBit((data >> i) & 0x01);
  }
  return bbReadAck();
}

bool bbWriteByte2WithLdacDrop(uint8_t data) {
  for (int i = 7; i >= 0; --i) {
    bbWriteBit((data >> i) & 0x01);
  }

  ldacLow();
  i2cDelay();
  return bbReadAck();
}

bool rewriteAddressBits(uint8_t oldAddress, uint8_t newAddress) {
  const uint8_t oldA = oldAddress & 0x07;
  const uint8_t newA = newAddress & 0x07;

  const uint8_t byte1 = static_cast<uint8_t>(0xC0 | (oldA << 1));
  const uint8_t byte2 = static_cast<uint8_t>(0b01100001 | (oldA << 2));
  const uint8_t byte3 = static_cast<uint8_t>(0b01100010 | (newA << 2));
  const uint8_t byte4 = static_cast<uint8_t>(0b01100011 | (newA << 2));

  Serial.printf("[I2C] 准备改址：0x%02X -> 0x%02X\n", oldAddress, newAddress);

  ldacHigh();
  delayMicroseconds(20);

  bbInitBus();
  bbStart();

  const bool ack1 = bbWriteByteNormal(byte1);
  Serial.printf("[I2C] 改址 ACK1=%s\n", ack1 ? "YES" : "NO");
  if (!ack1) {
    bbStop();
    ldacHigh();
    return false;
  }

  const bool ack2 = bbWriteByte2WithLdacDrop(byte2);
  Serial.printf("[I2C] 改址 ACK2=%s\n", ack2 ? "YES" : "NO");
  if (!ack2) {
    bbStop();
    ldacHigh();
    return false;
  }

  const bool ack3 = bbWriteByteNormal(byte3);
  Serial.printf("[I2C] 改址 ACK3=%s\n", ack3 ? "YES" : "NO");
  if (!ack3) {
    bbStop();
    ldacHigh();
    return false;
  }

  const bool ack4 = bbWriteByteNormal(byte4);
  Serial.printf("[I2C] 改址 ACK4=%s\n", ack4 ? "YES" : "NO");
  bbStop();
  ldacHigh();

  if (!ack4) {
    return false;
  }

  delay(120);
  return true;
}
}  // namespace

void MCP4728Driver::begin(TwoWire& wire) {
  wire_ = &wire;
  pinMode(kPinMcpLdac, OUTPUT);
  ldacHigh();
}

bool MCP4728Driver::probe(uint8_t address) const {
  if (wire_ == nullptr) {
    return false;
  }

  wire_->beginTransmission(address);
  return wire_->endTransmission(true) == 0;
}

bool MCP4728Driver::writeChannelCode(uint8_t address, uint8_t channel, uint16_t code) const {
  if (wire_ == nullptr) {
    return false;
  }

  const bool ok = multiWriteOne(*wire_, address, channel, code);
  if (!ok) {
    Serial.printf("[I2C] DAC 写入失败：地址=0x%02X，通道=%u，目标码=%u\n",
                  address,
                  channel,
                  code);
  }
  return ok;
}

bool MCP4728Driver::rewriteAddress(uint8_t oldAddress, uint8_t newAddress) const {
  if (wire_ == nullptr) {
    Serial.println("[I2C] 改址失败：I2C 尚未初始化");
    return false;
  }

  if (!isValidModuleAddress(oldAddress) || !isValidModuleAddress(newAddress)) {
    Serial.printf("[I2C] 改址失败：非法地址 old=0x%02X new=0x%02X\n", oldAddress, newAddress);
    return false;
  }

  if (oldAddress == newAddress) {
    Serial.printf("[I2C] 改址跳过：地址已是 0x%02X\n", oldAddress);
    return true;
  }

  wire_->end();
  const bool rewriteOk = rewriteAddressBits(oldAddress, newAddress);
  wire_->begin(kPinI2CSDA, kPinI2CSCL, kI2CFrequencyHz);

  if (!rewriteOk) {
    return false;
  }

  const bool probeOk = probe(newAddress);
  Serial.printf("[I2C] 改址结果：%s\n", probeOk ? "成功" : "失败");
  return probeOk;
}

}  // namespace orb
